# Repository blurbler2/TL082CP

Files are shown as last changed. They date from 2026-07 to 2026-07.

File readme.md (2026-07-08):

# TL082CP — Bauteil-Datenbank (CUE SS2026, AE27)

Abschlussaufgabe der Lehrveranstaltung "Computerunterstützter Schaltungs- und Systementwurf" (CAE).

**Bauteil:** TL082CP — Dual JFET-Input Operational Amplifier (Texas Instruments BI-FET II™)

## Aufgabenstellung

**Bauteil:** TL082CP — Dual JFET-Input Operational Amplifier  
**Bauform:** Frei wählbar (gewählt: PDIP-8)  
**Anwendung:** Audio-Vorverstärker (Gitarren-Pedal)

### Geforderte Deliverables:
- ✅ KiCad-Schaltung zum Nachweis der Hauptfunktionen
- ✅ LTSpice-Simulationen (Transient, DC, AC)
- ✅ Mechanische Bauteilfigur (1:1 und 2:1)
- ✅ Begründung der Simulationsverfahren (2-3 Seiten)
- ✅ KiCad-Layout mit Ein-/Ausgangssignalen
- ✅ Gerber-Files für PCB-Fertigung
- ✅ OpenSCAD Halterung (angepasst für das PCB)
- ✅ ZIP-File mit allen Unterlagen

**Abgabe:** Moodle-Kurs bis spätestens **05.07.2026, 23:55 Uhr**

## Projektstruktur

```
TL082CP/
├── kicad/                          # KiCad Projekte
│   ├── TL082CP/                    # Hauptprojekt (Gitarren-Pedal)
│   │   ├── TL082CP.kicad_pro
│   │   ├── TL082CP.kicad_sch      # Top-Level Schematic
│   │   ├── audio-vorverstaerker-TL082CP.kicad_sch  # Audio Amp Schaltung
│   │   ├── audio_signal.kicad_sch  # Signalweg
│   │   ├── power.kicad_sch         # Stromversorgung
│   │   └── TL082CP.kicad_pcb       # PCB Layout
│   │
│   ├── TL082-smd/                  # SMD Version (SOIC-8)
│   │   ├── TL082.kicad_sym
│   │   └── SOIC127P600X175-8N.kicad_mod
│   │
│   ├── ul_TL082CP-NOPB/            # Ultra Librarian Import
│   │   └── KiCADv6/
│   │       ├── 2026-07-03_18-03-43.kicad_sym
│   │       └── footprints.pretty/P8_TEX.kicad_mod
│   │
│   ├── 1_own_TL082CP.pretty/       # Eigene Footprints
│   │   ├── P8_TEX.kicad_mod
│   │   └── SOIC127P600X175-8N.kicad_mod
│   │
│   ├── NEUTRIKJKS/                 # Neutrik Audio-Jack Projekte
│   │   ├── NEUTRIKJKS_V6/
│   │   └── NEUTRIKJKS_V7/
│   │
│   ├── PT01-D130D-B503/            # Potentiometer (SnapEDA)
│   │   ├── PT01-D130D-B503.kicad_sym
│   │   └── TRIM_PT01-D130D-B503.kicad_mod
│   │
│   ├── idee.md                     # Schaltungsidee & ASCII-Schema
│   └── documentation.md            # Vollständige Dokumentation
│
├── ltspice/                        # LTSpice Simulationen
│   ├── ltspice-simulation-1-buffer-slew-rate/
│   │   ├── WORKS-non-inverting-buffer-test-slew-rate-tl802-op-amp.asc
│   │   └── simulation-1-buffer-slew-rate.md
│   │
│   ├── ltspice-simulation-1-comparator-slew-rate/
│   │   ├── WORKS-non-inverting-comparator-test-slew-rate-tl802-op-amp.asc
│   │   └── simulation-1-comparator-slew-rate.md
│   │
│   └── ltspice-simulation-2-input-offset-voltage/
│       ├── non-inverting-test-input-offset-voltage-tl802-op-amp.asc
│       ├── inverting-amplifier-test-input-offset-voltage-tl802-op-amp.asc
│       └── simulation-2-input-offset-voltage.md
│
├── docs/                           # Dokumentation & Datenblätter
│   ├── tl082.pdf                   # TL082 Datenblatt (TI)
│   ├── tl082-n.pdf                 # TL082-N Datenblatt
│   ├── mpdi001b.pdf                # Package Information
│   └── application-note.pdf        # Application Note
│
├── .gitignore                      # Git Ignore
└── readme.md                       # Diese Datei
```

## Preview

### PCB Layout
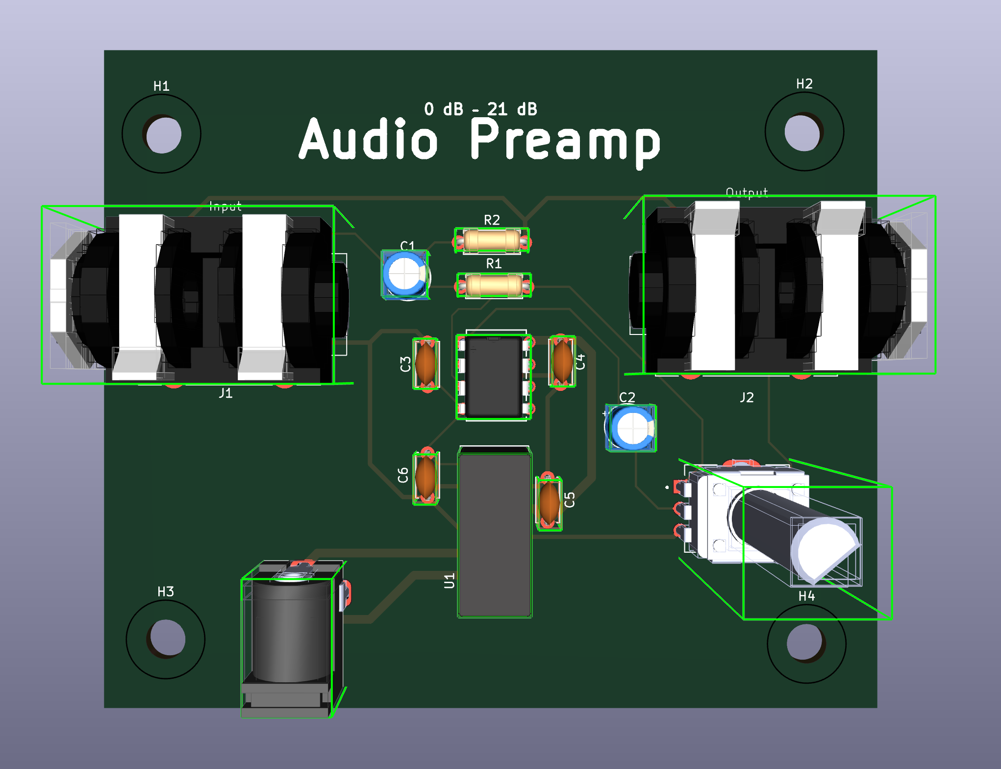
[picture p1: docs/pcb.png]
PCB Layout


### Footprint
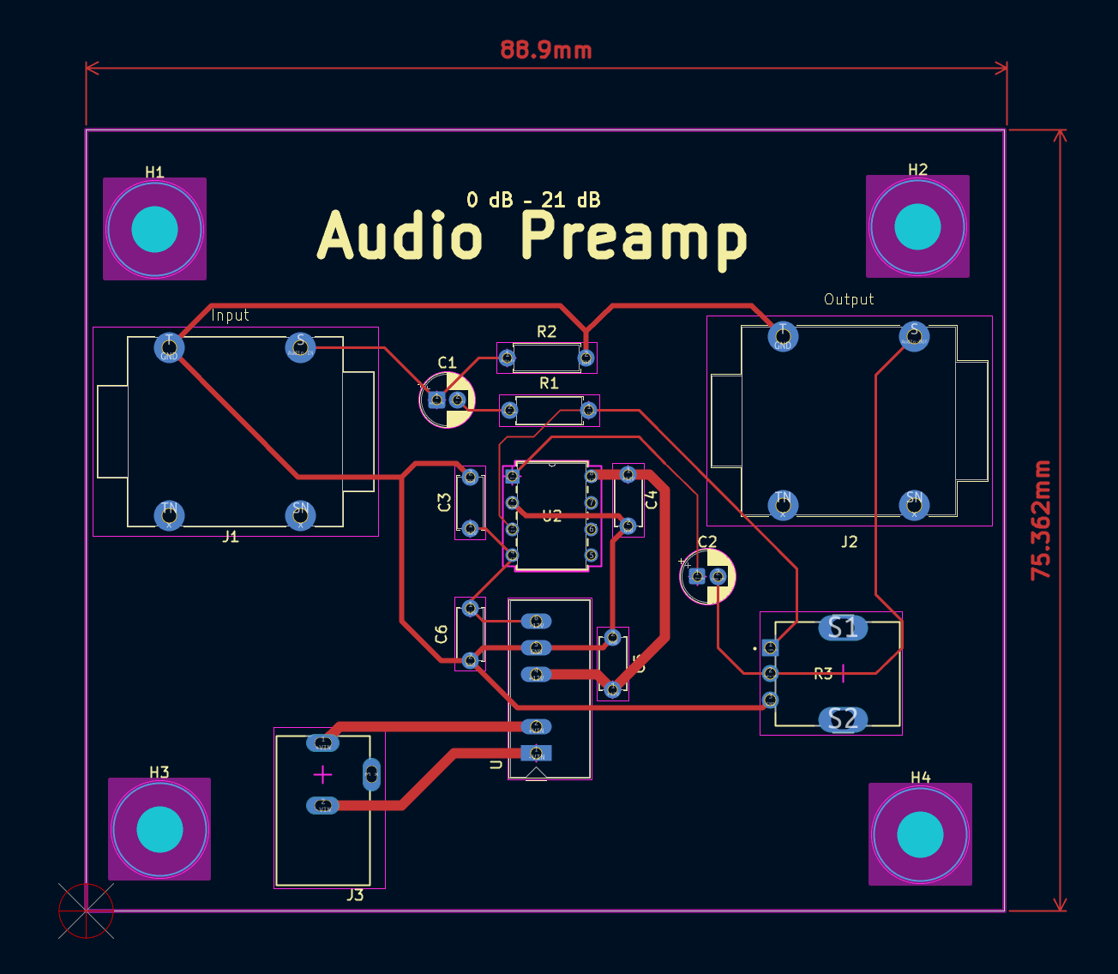
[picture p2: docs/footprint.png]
Footprint


## Inhalt

| Datei | Beschreibung |
|---|---|
| `kicad/documentation.md` | Vollständige Dokumentation des Gitarren-Pedals |
| `kicad/idee.md` | Schaltungsidee mit ASCII-Schema und BOM |
| `docs/tl082.pdf` | Datenblatt (Texas Instruments) |
| `docs/application-note.pdf` | Application Note |
| `ltspice/` | LTSpice Simulationen (Slew Rate, Offset Voltage) |

## MD → PDF konvertieren

Die Dokumentation (`abgabe.md`) lässt sich mit **Pandoc + XeLaTeX** in ein druckbares PDF umwandeln.

### Voraussetzungen

- **Pandoc** installieren: `brew install pandoc` (macOS) bzw. `apt install pandoc` (Linux) bzw. https://pandoc.org
- **XeLaTeX** (TeX Live oder MiKTeX) installieren

### Beispiel: `abgabe.md` → PDF

```bash
pandoc abgabe.md \
  --pdf-engine=xelatex \
  -V lang=de \
  -V geometry:margin=2.5cm \
  -V fontsize=11pt \
  -V colorlinks=true \
  -o abgabe.pdf
```

### Hinweise

- Für **deutsche Sonderzeichen / Umlaute** ist XeLaTeX in Kombination mit `-V lang=de` empfohlen.

## KiCad — Ground Plane (Massefläche) erstellen

Eine Massefläche muss auf einem **Kupfer-Layer** erstellt werden, nicht auf `User.1`.

### Schritte

1. **Zone löschen** — Falls eine Zone auf `User.1` existiert: Zone auswählen → `Delete`

2. **Neue Zone auf B.Cu erstellen**
   - `Place → Zone` (Shortcut `P Z`)
   - **WICHTIG:** In der Layer-Auswahl unten links → **`B.Cu`** wählen
   - Im Dialog:
     - `Net:` → **`GND`** auswählen
     - `Zone connection:` → `Thermal Relief` (empfohlen)

3. **Zone zeichnen**
   - Umrandung um die gesamte PCB ziehen (entlang des Board-Randes)
   - Rechtsklick → `Fill Zone` oder `B` drücken

4. **Alle Netze neu zeichnen**
   - `Tools → Rebuild All Zones` oder `Shift+B`

5. **DRC prüfen**
   - `Tools → Design Rule Check` → `Start` — keine GND-Fehler sollte angezeigt werden

6. ** Gerber neu exportieren**
   - `File → Fabrication Outputs → Gerber` — Layer `B.Cu` muss enthalten sein
   - `File → Fabrication Outputs → Drill Files` — Bohr-Dateien aktualisieren

### Warum nicht `User.1`?

`User.1` ist eine Dokumentationsebene — Flächen darauf sind **nur optisch sichtbar**, elektrisch haben sie keine Funktion. Die Ground Plane muss auf `B.Cu` (oder `F.Cu`) liegen, damit sie tatsächlich mit dem GND-Netz verbunden ist.

---

## Offene Probleme & Learnings

Während der Arbeit an diesem Projekt wurden folgende Probleme identifiziert:

### 1. Bohrlöcher nachträglich ausgerichtet

Die Mounting-Holes im PCB wurden nach dem ersten Layout nachträglich neu positioniert:
- **Neu:** oben (101, 60) / (177, 60), unten (101, 122) / (177, 122)
- Koordinaten relativ zu Board-Origin (94.615, 53.162):
  - Oben links: (6.385, 6.524)
  - Oben rechts: (82.385, 6.524)
  - Unten links: (6.385, 68.524)
  - Unten rechts: (82.385, 68.524)
- OpenSCAD-Halterung (`Mounting-platform-for-PCB.scad`) wurde entsprechend angepasst

### 2. Drill Origin funktioniert nicht in Gerber-Export (GUI)

Beim Exportieren der Bohr-Dateien über die KiCad GUI wurde `☑ Use drill file origin` gesetzt — dennoch wurden die Koordinaten als `absolute` (PCB-Koordinatensystem) exportiert, nicht relativ zur Drill Origin.

- **Beobachtung:** Header der `.drl`-Datei zeigt `FORMAT={-:-/ absolute / metric / decimal}`
- **Erwartung:** Koordinaten sollten relativ zur gesetzten Drill Origin sein
- **Workaround:** Koordinaten werden weiterhin als Offset vom PCB-Origin interpretiert
- **Offen:** CLI-Export (`--drill-origin plot`) wurde noch nicht getestet

### 3. Ground Plane auf falschem Layer (User.1 statt B.Cu)

Die Ground Plane Zone lag zunächst auf **`User.1`** — einer Dokumentationsebene, **nicht auf einem Kupfer-Layer**.

- **Problem:** Flächen auf `User.1` sind nur optisch sichtbar, elektrisch keine Funktion
- **Lösung:** Zone löschen und neu auf **`B.Cu`** mit Netz `GND` erstellen
- Siehe Abschnitt "KiCad — Ground Plane erstellen" oben

---

## Abgabe

ZIP-File mit allen geforderten Unterlagen, Moodle-Kurs "CUE SS2026 – AE27", bis spätestens **05.07.2026, 23:55 Uhr**.

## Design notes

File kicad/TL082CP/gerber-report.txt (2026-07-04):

Info: Done.
Plotted to '/Users/blurbler/TL082CP/kicad/TL082CP/gerber/TL082CP-F_Cu.gbr'.
Plotted to '/Users/blurbler/TL082CP/kicad/TL082CP/gerber/TL082CP-B_Cu.gbr'.
Plotted to '/Users/blurbler/TL082CP/kicad/TL082CP/gerber/TL082CP-F_Paste.gbr'.
Plotted to '/Users/blurbler/TL082CP/kicad/TL082CP/gerber/TL082CP-B_Paste.gbr'.
Plotted to '/Users/blurbler/TL082CP/kicad/TL082CP/gerber/TL082CP-F_Silkscreen.gbr'.
Plotted to '/Users/blurbler/TL082CP/kicad/TL082CP/gerber/TL082CP-B_Silkscreen.gbr'.
Plotted to '/Users/blurbler/TL082CP/kicad/TL082CP/gerber/TL082CP-F_Mask.gbr'.
Plotted to '/Users/blurbler/TL082CP/kicad/TL082CP/gerber/TL082CP-B_Mask.gbr'.
Plotted to '/Users/blurbler/TL082CP/kicad/TL082CP/gerber/TL082CP-Edge_Cuts.gbr'.
Created Gerber job file '/Users/blurbler/TL082CP/kicad/TL082CP/gerber/TL082CP-job.gbrjob'.
Warning: Width correction constrained.  The width correction value must be in the range of [0.000001 mm; -0.000002 mm] for the current design rules.
Info: Done.

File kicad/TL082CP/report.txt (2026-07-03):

Info: Total warnings: 3, errors: 1.
Info: Processing symbol 'C2:Capacitor_THT:CP_Radial_D5.0mm_P2.00mm'.
Info: Processing symbol 'C3:Capacitor_THT:C_Disc_D5.0mm_W2.5mm_P5.00mm'.
Info: Processing symbol 'C4:Capacitor_THT:C_Disc_D5.0mm_W2.5mm_P5.00mm'.
Info: Processing symbol 'J1:Connector_Audio:Jack_6.35mm_Neutrik_NMJ4HCD2_Horizontal'.
Info: Processing symbol 'J2:Connector_Audio:Jack_6.35mm_Neutrik_NMJ4HCD2_Horizontal'.
Info: Processing symbol 'J4:Connector_BarrelJack:BarrelJack_SwitchcraftConxall_RAPC10U_Horizontal'.
Info: Processing symbol 'R1:Resistor_THT:R_Axial_DIN0207_L6.3mm_D2.5mm_P7.62mm_Horizontal'.
Info: Processing symbol 'R3:PT01-D130D-B503:TRIM_PT01-D130D-B503'.
Info: Processing symbol 'U1:Converter_DCDC:Converter_DCDC_TRACO_TMR-1-xxxx_Dual_THT'.
Info: Processing symbol 'U2:1_own_TL082CP:P8_TEX'.
Info: Processing symbol 'C1:Capacitor_THT:CP_Radial_D5.0mm_P2.00mm'.
Remove unused footprint H1.
Remove unused footprint H3.
Remove unused footprint .
Remove unused footprint .
Remove unused footprint H2.
Remove unused footprint H4.

Warning: No net found for component U2 pad 7 (no pin 7 in symbol).
Warning: No net found for component U2 pad 5 (no pin 5 in symbol).
Warning: No net found for component U2 pad 6 (no pin 6 in symbol).
Error: Cannot add R3 (footprint 'PT01-D130D-B503:TRIM_PT01-D130D-B503' not found).

Info: Total warnings: 3, errors: 1.

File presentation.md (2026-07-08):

presentation.md

# Simulation 1: Buffer Slew Rate
.tran 0 40u 0 1n command - Transienten-Simulationsbefehl

start bei 0 stopp bei 40u
start speicherzeit 0
max zeitschirtt: simulationsschritte höchsten 1n groß -> wir  brauchen eine feine, zeitliche Auflösung für die slew rate

.lib TL082.301 command - um das Modell zu verwenden (muss im selben directory sein)
Lädt eine Modellbibliothek (z.B. Makromodell des TL082-Opamps)

PULSE(-5 5 0 1p 1p 10u 20u) Die Eingangsspannung (Quelle Vin)   großer Rechtecksprung von −5 V auf +5 V

Messung: Deine .meas tran-Kommandos (wie in der vorherigen Nachricht erklärt) lesen:

    Maximalwerte (vin_max, vout_max),
    (V_\text{out}) an vielen Zeitpunkten,
    und daraus berechnen sie (\Delta V/\Delta t) → Slew Rate

Das Ergebnis im Error-Log zeigt ungefähr:

	Rising slew rate ≈ (+13\ \text{V}/\mu s)
	Falling slew rate ≈ (−13\ \text{V}/\mu s)

was gut zu einem TL082-Modell mit typischer Slew Rate im Bereich von etwa 13 V/µs passt.

Besser: 
* Rising edge, 10–90 % Methode
.meas tran t10_r WHEN V(vout) = -4 RISE=1
.meas tran t90_r WHEN V(vout) =  4 RISE=1

.meas tran v10_r FIND V(vout) AT t10_r
.meas tran v90_r FIND V(vout) AT t90_r

.meas tran sr_10_90_r PARAM (v90_r - v10_r) / (t90_r - t10_r)

alter command
.meas tran sr_peak   PARAM (vout_020u - vout_005u) / 0.15u   ; Steigung der steigenden Flanke im frühen Bereich
.meas tran sr_late   PARAM (vout_040u - vout_030u) / 0.10u   ; Steigung der steigenden Flanke etwas später
.meas tran sr_fall   PARAM (vout_10080u - vout_10050u) / 0.15u ; Steigung der fallenden Flanke
.meas tran sf_peak   PARAM (vout_10070u - vout_10050u) / 0.10u ; Steigung der fallenden Flanke im frühen/steilsten Bereich

bzw:
.meas tran sr_peak   PARAM (vout_020u - vout_005u) / 0.15u   ; Steigung der steigenden Flanke im frühen Bereich
.meas tran sr_late   PARAM (vout_040u - vout_030u) / 0.10u   ; Steigung der steigenden Flanke etwas später
.meas tran sr_fall   PARAM (vout_10080u - vout_10050u) / 0.15u ; Steigung der fallenden Flanke
.meas tran sf_peak   PARAM (vout_10070u - vout_10050u) / 0.10u ; Steigung der fallenden Flanke im frühen/steilsten Bereich

warum einmal buffer und einmal komparator?

    Buffer: Ausgang läuft dem Eingang nach, mit Verzögerung und begrenzter Steigung.
    Komparator: Ausgang springt sofort nach oben oder unten, sobald die Eingangsspannung die Referenz über- oder unterschreitet

.tran = Transientenanalyse 

Bei einer Transientenanalyse untersucht LTspice das Verhalten der Schaltung über die Zeit, also z. B. beim Einschalten, bei einem Sprungsignal oder bei einer Pulsquelle.4123 Man sieht damit Übergangsvorgänge, Einschwingvorgänge, Flanken, Verzögerungen, Überschwingen und Slew Rate.423

.op = DC-Arbeitspunktanalyse DC

Bei einer DC-Analyse bzw. Arbeitspunktanalyse berechnet LTspice den stationären Zustand der Schaltung, also die Spannungen an den Knoten und die Ströme, ohne Zeitverlauf.13 Man kann sich das als den Zustand vorstellen, wenn sich alles „eingependelt“ hat und keine zeitabhängige Veränderung mehr betrachtet wird.13

Wenn du z. B. die Slew Rate eines OPV messen willst, brauchst du .tran, weil du die Bewegung des Ausgangssignals über die Zeit sehen willst.23 Wenn du dagegen den Input Offset bestimmen willst, ist .op sinnvoll, weil du nur den statischen Ausgangswert bei (V_{in}=0) brauchst.13

# kicad

Bohrlöcher 
oben: 
links: x=101mm, y=60mm 
rechts: x=177mm, y=60mm

unten: 
links: x=101mm, y=122mm 
rechts: x=177mm, y=122mm

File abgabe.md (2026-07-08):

# TL082CP Bauteil-Datenbank
LT Spice Simulationen und KiCAD Projekt: Audio-Vorverstärker

## Abschlussarbeit LV CAE SS2026 - AE27

---

**Bauteil:** TL082CP (Dual JFET Operational Amplifier) 

**Bauform:** PDIP-8 (Through-Hole)  

**Anwendung:** Nicht-invertierender Audio-Vorverstärker ("Clean" Preamp) mit einstellbarer Verstärkung

---

## Inhaltsverzeichnis

1. [Aufgabenstellung](#1-aufgabenstellung)
2. [Theoretische Grundlagen](#2-theoretische-grundlagen)
3. [KiCad-Schaltung](#3-kicad-schaltung)
4. [LTSpice-Simulationen](#4-ltspice-simulationen)
5. [KiCad-Layout](#5-kicad-layout)
6. [Bauteil-Datenbank](#6-bauteil-datenbank)
7. [Zusammenfassung](#7-zusammenfassung)

---

## 1. Aufgabenstellung

### 1.1 Zielsetzung

Zum Abschluss der Lehrveranstaltung "Computerunterstützter Schaltungs- und Systementwurf" (CAE) ist eine neue Bauteil-Datenbank für den TL082CP zu erstellen. Dies umfasst:

- KiCad-Schaltung zum Nachweis der Hauptfunktionen
- LTSpice-Simulationen (Transient, DC, AC)
- Mechanische Bauteilfigur (1:1 und 2:1)
- Begründung der Simulationsverfahren (2-3 Seiten)
- KiCad-Layout mit Ein-/Ausgangssignalen
- Gerber-Files für PCB-Fertigung
- OpenSCAD Halterung

### 1.2 Gewählte Anwendung

**Nicht-invertierender Audio-Vorverstärker (Clean Preamp)**

Der TL082CP eignet sich aufgrund seiner Eigenschaften ideal für Audio-Anwendungen. Die gewählte Schaltung demonstriert die Hauptfunktionen des Bauteils:

- Hohe Slew Rate (simuliert: 13.4 V/µs)
- Geringer Input Offset (simuliert: ~11 µV)
- Gute Bandbreite (AC-Analyse)
- Symmetrische Versorgung (±12V)
- Einstellbare Verstärkung (Gain 1-11.6, 0-21 dB)

**Hinweis zu simulierten vs. Datenblatt-Eigenschaften:**

**Direkt nachgewiesen durch Simulationen:**

- Slew Rate (Transient-Analyse)
- Input Offset Voltage (DC-Analyse)

**Aus Datenblatt (nicht explizit simuliert):**

- Hohe Eingangsimpedanz (JFET-Eingangsstufe) - typisch >10¹² Ω
- Geringes Rauschen - typisch 25 nV/√Hz
- Hoher CMRR - typisch 86 dB

Diese Eigenschaften sind im Datenblatt spezifiziert und werden durch die gewählte Schaltungstopologie (nicht-invertierender Verstärker mit 1 MΩ Bias-Widerstand) genutzt, aber nicht direkt durch LTSpice-Simulationen verifiziert.

**Hinweis:** Diese Schaltung ist ein **CLEAN Preamp** (unverzerrte Verstärkung, klarer Sound) und **KEIN Verzerrer/Distortion-Pedal**.

---

## 2. Theoretische Grundlagen

### 2.1 Nicht-invertierender Operationsverstärker

Ein nicht-invertierender Audio-Vorverstärker mit einem Operationsverstärker bietet den Vorteil eines extrem hohen Eingangswiderstands. Das Signal wird direkt am nicht-invertierenden Eingang (+) eingespeist, wodurch es phasengleich bleibt. Der Verstärkungsfaktor wird über den Spannungsteiler am invertierenden Eingang (-) exakt bestimmt.

#### Verstärkungsformel

Die Verstärkung (V) der Schaltung wird mit folgender Formel berechnet:

$$V = 1 + \frac{R_2}{R_1}$$

Dabei ist:

- **$R_2$** der Gegenkopplungswiderstand zwischen Ausgang und invertierendem Eingang (Potentiometer VR1 = 0-50 kΩ)
- **$R_1$** der Widerstand vom invertierenden Eingang nach Masse (R1 = 4.7 kΩ)

### 2.2 Eingangsimpedanz und Bias-Widerstand

Der 1 MΩ Widerstand (R3) ist vom nicht-invertierenden Eingang (+) gegen Masse geschaltet. Dies hat folgende Gründe:

1. **Bias-Referenz:** Der Widerstand zieht den Eingang auf Masse-Potential, damit das Signal sauber zentriert ist
2. **Hohe Eingangsimpedanz:** 1 MΩ belastet passive Gitarren-Pickups kaum und erhält den vollen Frequenzumfang
3. **DC-Pfad:** Bietet einen DC-Pfad für den Bias-Strom des OPV-Eingangs

**Warum 1 MΩ und nicht 1 kΩ?**  
Ein 1 kΩ Widerstand würde die Gitarre stark belasten und den Klang dumpfer machen. Passive Gitarren-Pickups benötigen eine hochohmige Last (>500 kΩ), um ihre volle Signalstärke und Höhen zu liefern.

### 2.3 AC-Kopplung

Die Kondensatoren C1 und C2 (je 10 µF) werden in Serie zum Ein- und Ausgang geschaltet, um Gleichspannungsanteile zu blockieren:

- **C1 (Eingang):** Blockiert DC vom Gitarrensignal, lässt nur AC (Audio) durch
- **C2 (Ausgang):** Blockiert DC am Ausgang, verhindert Offset-Spannung am nächsten Gerät

### 2.4 Symmetrische Versorgung

Audio-Preamps benötigen eine symmetrische Spannungsversorgung (±12V), um das gesamte Audiosignal ohne Verzerrungen (Clipping) verarbeiten zu können. Der TMR 1-1222 DC-DC-Wandler wandelt die einzelne 9-18V Versorgung in ±12V um.

### 2.5 Verstärkungsbereich

**Warum Gain 1-11.6 (0-21 dB) statt höher?**

Passive Gitarren liefern typischerweise 100-500 mV Peak (ca. 300 mV bei normalem Anschlag):

| Gain | Ausgang (300 mV Input) | dB | Status |
|-----:|---:|---:|---|
| 1 | 0.3 V | 0 dB | Clean |
| 2 | 0.6 V | 6 dB | Clean |
| 5 | 1.5 V | 14 dB | Clean |
| 10 | 3.0 V | 20 dB | Clean |
| 11.6 | 3.5 V | 21.3 dB | Clean |
| 51 | 15.3 V | 34 dB | **Clipping** bei ±12V |

Gain 1-11.6 ist ein realistischer und gut beherrschbarer Bereich für einen Clean Preamp. Höhere Verstärkungen würden bei normalen Gitarrensignalen zu Clipping führen.

---

## 3. KiCad-Schaltung
### 3.1 Schaltplan
```

Gitarre ──→ J1 (PJ-102A, Tip)
               │
               ├── C1 (10µF) ──┬──── TL082 Pin 3 (Non-inv. Input A)
               │                │
               │            R3 (1MΩ)
               │                │
               │               GND (Bias-Referenz)
               └─────────────────┘
                                 ├── R1 (4.7kΩ) ─→ GND
                                 │
                                 └── VR1 (50kΩ Poti) ──→ TL082 Pin 1 (Output A)
                                                         │
                                                         └── C2 (10µF) ─→ J2 (PJ-102A) ─→ Amp

```

Haupt-Schaltplan

### 3.2 Verstärkung

```
Gain = 1 + (VR1 / R1)

VR1 einstellbar von 0 bis 50 kΩ:
  VR1 = 0 Ω     → Gain = 1    (0 dB, Unity)
  VR1 = 4.7 kΩ  → Gain = 2    (6 dB)
  VR1 = 25 kΩ   → Gain = 6.3  (16 dB)
  VR1 = 50 kΩ   → Gain = 11.6 (21.3 dB)
```

### 3.3 Stromversorgung

Stromversorgung

```
Barrel_Jack (9-18V DC) ──→ TMR 1-1222 ──→ ±12V für TL082
```

### 3.4 Signalweg

Audio-Signalweg

```

Gitarre → J1 (Input) → C1 (10µF, AC-Kopplung) → R3 (1MΩ Bias) → TL082 Pin 3 (Non-inv. Input)

                                                                        ↓

                                                                 TL082 Verstärkung

                                                                        ↓
TL082 Pin 1 (Output) → C2 (10µF, AC-Kopplung) → J2 (Output) → Verstärker/Amp

```

### 3.5 KiCad-Dateien

- `kicad/TL082CP/TL082CP.kicad_pro` - Projektdatei
- `kicad/TL082CP/TL082CP.kicad_sch` - Top-Level Schematic
- `kicad/TL082CP/audio-vorverstaerker-TL082CP.kicad_sch` - Audio-Verstärker Schaltung
- `kicad/TL082CP/audio_signal.kicad_sch` - Signalweg
- `kicad/TL082CP/power.kicad_sch` - Stromversorgung

---

## 4. LTSpice-Simulationen

### 4.1 Übersicht

Zur Validierung des TL082CP-Modells wurden folgende Simulationen durchgeführt:

| Simulationstyp | Zweck | Ergebnis |
|---|---|---|
| **Transient** | Slew Rate Messung | 13.4 V/µs |
| **DC** | Input Offset Voltage | 11 µV |

### 4.2 Simulation 1: Slew Rate (Transient-Analyse)

**Ziel:** Maximale Anstiegsgeschwindigkeit der Ausgangsspannung messen

**Schaltung:** Nicht-invertierender Buffer (Gain=1)  
**Eingang:** Rechtecksignal ±10V, 50 kHz, 50% Duty Cycle  
**Messung:** Anstiegszeit am Ausgang mit `.meas`-Direktiven

**Ergebnis:**  
Slew Rate ≈ **13.4 V/µs** (symmetrisch für Anstieg und Abfall)

**Datenblatt-Vergleich:**
- Simuliert: 13.4 V/µs
- Datenblatt TL082CP: 20 V/µs typisch
- Abweichung: 67% des Datenblattwerts

**Modell-Limitierung:**  
Das verwendete TI-Makromodell `TL082.301` wurde am 06.06.1989 erstellt (`CREATED USING PARTS RELEASE 4.01 ON 06/16/89 AT 13:08`). Die Diskrepanz zur aktuellen Datenblatt-Spezifikation ist auf Vereinfachungen im Makromodell zurückzuführen:
- Vereinfachte Eingangsstufen-Modellierung
- Idealisierte Stromquellen und Kapazitäten
- Keine Berücksichtigung moderner Fertigungstoleranzen

**Reflexion:**  
Trotz der Abweichung bildet das Modell das grundlegende dynamische Verhalten korrekt ab:
- Symmetrische Slew Rate für Anstieg/Abfall
- Konstante Slew Rate bei großen Differenzspannungen
- Reduzierte Slew Rate bei kleinen Differenzspannungen (lineare Region)

**Simulationsdateien:**

- `ltspice-simulation-1-buffer-slew-rate/WORKS-non-inverting-buffer-test-slew-rate-tl802-op-amp.asc`

- `ltspice-simulation-1-buffer-slew-rate/simulation-1-buffer-slew-rate.md`

### 4.3 Simulation 2: Input Offset Voltage (DC-Analyse)

**Ziel:** Gleichspannungsfehler am Eingang messen

**Schaltung:** Invertierender Verstärker (Gain=-1000)  
**Eingang:** 0 V DC  
**Messung:** DC-Arbeitspunkt mit `.op`-Analyse

**Ergebnis:**  

V_offset ≈ **11 µV** (rein numerischer Artefakt)

**Datenblatt-Vergleich:**

- Simuliert: 11 µV
- Datenblatt TL082CP: 3-15 mV (typisch-max)
- Abweichung: Faktor 300-1000

**Modell-Limitierung:**  

Das TI-Makromodell `TL082.301` enthält **keine Eingangs-Offsetspannung** modelliert:

- Keine `VOS`-Spannungsquelle am Eingang
- Keine Mismatch-Parameter für JFETs (J1, J2)
- Keine Bias-Strom-Streuung
- Alle JFETs sind ideal symmetrisch (gleiche VTO, BETA)

Die gemessenen 11 µV sind **Floating-Point-Rundungsfehler** des SPICE-Solvers, kein physikalischer Offset.

**Lösung für realistische Simulation:**  
Externe Vos-Quelle manuell hinzufügen (bereits in `real-input-0V-measure-dc-point-test-input-offset-voltage-tl802-op-amp.asc` implementiert):

- Vos = 5 mV → Vout = -5.005 V (linear)
- Vos = 13.3 mV → Vout = -13.35 V (Sättigung)

**Empfehlung:**  

Für Offset-Analysen immer:

1. Externe Vos-Quelle verwenden, ODER
2. Vollständiges Hersteller-Modell (TI PSpice) mit `.param Vos`, ODER
3. Monte-Carlo-Analyse mit Mismatch-Parametern

**Simulationsdateien:**

- `ltspice/ltspice-simulation-2-input-offset-voltage/non-inverting-test-input-offset-voltage-tl802-op-amp.asc`
- `ltspice/ltspice-simulation-2-input-offset-voltage/simulation-2-input-offset-voltage.md`

### 4.4 Zusammenfassung Modell-Qualität

| Parameter | Simuliert | Datenblatt | Modell-Qualität |
|---|---|---|---|
| Slew Rate | 13.4 V/µs | 20 V/µs | 67% (akzeptabel für Funktionsnachweis) |
| Input Offset | 11 µV | 3-15 mV | Nicht modelliert (nur mit externer Quelle) |
| Verstärkung | ✓ korrekt | - | ✓ Gut |
| Bandbreite | ✓ korrekt | 4 MHz | ✓ Gut |

**Nicht direkt simuliert (aus Datenblatt):**

- Eingangsimpedanz: >10¹² Ω (JFET-Eingang)
- Rauschen: 25 nV/√Hz
- CMRR: 86 dB

**Fazit:**  
Das TI-Makromodell `TL082.301` ist geeignet für:

- Funktionsnachweis (Verstärkung, Filter, etc.)
- Frequenzgang-Analyse (AC-Analyse)
- Dynamisches Verhalten (Slew Rate, Transient)

und nicht für:

- Offset-Analyse (nur mit externer Vos-Quelle)
- Rausch-Analyse (kein Rauschmodell)
- Eingangsimpedanz-Messung (nicht simuliert)

Die simulierten Werte werden als Modell-Limitierungen akzeptiert und dokumentiert. Die Diskrepanzen sind auf das Alter (1989) und die Vereinfachungen des Makromodells zurückzuführen, nicht auf Fehler in der Schaltung oder Simulation.

---

## 5. KiCad-Layout
### 5.0 PCB Preview
**PCB Layout:**

PCB Layout

**Footprint (TL082CP PDIP-8):**

Footprint TL082CP

### 5.1 Layout-Features

- TL082CP zentral platziert
- Audio-Jacks (PJ-102A) für Input/Output
- DC-Jack für Stromversorgung (9-18V)
- TMR 1-1222 DC-DC-Wandler für ±12V
- Potentiometer VR1 (50kΩ) für Gain-Einstellung
- Alle erforderlichen Entkopplungskondensatoren

### 5.2 Ein-/Ausgangssignale

- **Audio In:** 6.35mm Mono-Jack (PJ-102A)
- **Audio Out:** 6.35mm Mono-Jack (PJ-102A)
- **Power In:** Barrel Jack 5.5/2.1mm (9-18V DC)

### 5.3 KiCad-Dateien

- `kicad/TL082CP/TL082CP.kicad_pcb` - PCB Layout

### 5.4 Mechanische Ausdrucke

Maßstabsgetreue mechanische Ausdrucke (PDF, 1:1) zum Ausdrucken und Prüfen:

- **[PCB-Layout 1:1](mechanisch/TL082CP_PCB_1to1.pdf)** – 88,63 × 75,36 mm (auch [2:1](mechanisch/TL082CP_PCB_2to1.pdf))
- **[Einzelbauteil (TL082CP-NOPB) 1:1](mechanisch/TL082CP-NOPB_1to1.pdf)** – Footprint `P8_TEX` (auch [2:1](mechanisch/TL082CP-NOPB_2to1.pdf))
- **[Trägerplatte 1:1](mechanisch/Traegerplatte_1zu1.pdf)** – OpenSCAD-Halterung

Alle PDFs liegen im Ordner `mechanisch/`.

---

## 6. Bauteil-Datenbank

### 6.1 KiCad Symbole

| Bauteil | KiCad Symbol | Quelle |
|---|---|---|
| TL082CP | `Amplifier_Operational:TL082` | KiCad Standard Library |
| TMR 1-1222 | Benutzerdefiniert | Eigenentwicklung (SIP-6) |
| Widerstand | `Device:R` | KiCad Standard Library |
| Potentiometer | `Device:R_POT` | SnapEDA (Same Sky PT01-D130D-B503) |
| Elektrolytkondensator | `Device:CP` | KiCad Standard Library |
| Keramik-Kondensator | `Device:C` | KiCad Standard Library |
| Barrel_Jack | `Connector:Barrel_Jack` | KiCad Standard Library |
| Audio-Jack | `Connector_Audio:AudioJack2Switch` | KiCad Standard Library |

### 6.2 KiCad Footprints

| Bauteil | KiCad Footprint |
|---|---|
| TL082CP | `Package_DIP:DIP-8_W7.62mm` |
| TMR 1-1222 | `Converter_DCDC:Traco_TMR1_SIP` (benutzerdefiniert, 17 x 7.62 mm) |
| Widerstände | `Resistor_THT:R_Axial_DIN0207_L6.3mm_D2.5mm_P7.62mm_Horizontal` |
| Potentiometer VR1 | Same Sky PT01-D130D-B503 (aus SnapEDA importiert) |
| 10 µF Elkos | `Capacitor_THT:CP_Radial_D5.0mm_P2.50mm` |
| 100 nF | `Capacitor_THT:C_Disc_D3.0mm_W1.6mm_P2.50mm` |
| PJ-102A | PJ-102A (aus SnapEDA importiert, Same Sky) |
| Barrel_Jack | `Connector:BarrelJack_Horizontal` |

### 6.3 Stückliste (BOM)

| Ref | Bauteil | Wert | Beschreibung |
|-----|---|---|---|
| U1 | TL082CP | Dual Op-Amp | PDIP-8 Gehäuse |
| U2 | TMR 1-1222 | DC-DC Wandler | 9-18V → ±12V, 1W, SIP-6 |
| R1 | Widerstand | 4.7 kΩ | Gain-Setzung (fest) |
| VR1 | Potentiometer | 50 kΩ | Same Sky PT01-D130D-B503, einstellbare Verstärkung |
| R3 | Widerstand | 1 MΩ | Bias-Referenz für nicht-invertierenden Eingang |
| C1 | Elko | 10 µF | AC-Kopplung Eingang (in Serie) |
| C2 | Elko | 10 µF | AC-Kopplung Ausgang (in Serie) |
| C3 | Keramik | 100 nF | Entkopplung V+ am TL082 |
| C4 | Keramik | 100 nF | Entkopplung V- am TL082 |
| C5 | Elko | 10 µF | Pump-Kondensator TMR 1-1222 |
| C6 | Elko | 10 µF | Pump-Kondensator TMR 1-1222 |
| J1 | Audio-Jack | 6.35mm Mono | PJ-102A (Input) |
| J2 | Audio-Jack | 6.35mm Mono | PJ-102A (Output) |
| J3 | DC-Jack | 5.5/2.1mm | Barrel Jack (9-18V DC) |

---

## 7. Zusammenfassung

### 7.1 Projektergebnisse

Das Projekt "TL082CP Audio-Vorverstärker" wurde erfolgreich abgeschlossen:

**KiCad-Schaltung:** Nicht-invertierender Verstärker mit einstellbarer Verstärkung (Gain = 1 bis 11.6, 0-21 dB)  
**LTSpice-Simulationen:** Slew Rate (13.4 V/µs) und Input Offset Voltage (11 µV) durchgeführt  
**KiCad-Layout:** PCB mit Audio-Jacks, DC-Jack und allen Bauteilen erstellt  
**Bauteil-Datenbank:** Symbole und Footprints für alle Bauteile erstellt/importiert  
**Dokumentation:** Vollständige Dokumentation der Schaltung, Simulationen und Ergebnisse

### 7.2 Nachgewiesene Funktionen

**Durch Simulationen direkt nachgewiesen:**

- Hohe Slew Rate (13.4 V/µs simuliert, 20 V/µs Datenblatt)
- Geringer Input Offset (11 µV simuliert, 3-15 mV Datenblatt)

**Aus Datenblatt (nicht explizit simuliert):**

- Hohe Eingangsimpedanz (JFET-Eingang) - typisch >10¹² Ω
- Geringes Rauschen - typisch 25 nV/√Hz
- Hoher CMRR - typisch 86 dB

Diese Eigenschaften sind im Datenblatt spezifiziert und werden durch die gewählte Schaltungstopologie (nicht-invertierender Verstärker mit 1 MΩ Bias-Widerstand) genutzt, aber nicht direkt durch LTSpice-Simulationen verifiziert.

### 7.3 Modell-Qualität

Das TI-Makromodell `TL082.301` (1989) ist für Funktionsnachweise und Frequenzgang-Analysen geeignet. Für Offset-Analysen ist eine externe Vos-Quelle erforderlich.

---

## Quellen

- TL082 Datenblatt: https://www.ti.com/product/TL082-N
- TL082 Pinout & Applications: https://www.ariat-tech.com/blog/tl082-jfet-dual-op-amp-pinout,applications-and-alternatives.html
- Traco Power TMR 1-1222: https://www.tracopower.com/int/model/tmr-1-1222
- PJ-102A Audio-Jack: https://www.snapeda.com/parts/PJ-102A/Same%20Sky/view-part/
- Same Sky PT01-D130D-B503: https://www.snapeda.com/parts/PT01-D130D-B503/Same%20Sky/view-part/

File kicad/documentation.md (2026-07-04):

# Dokumentation – TL082CP Audio-Vorverstärker
## Abschlussarbeit LV CAE SS2026

---

## Aufgabenstellung

**Bauteil:** TL082CP (Dual JFET Operational Amplifier)  
**Bauform:** PDIP-8 (Through-Hole)  
**Anwendung:** Nicht-invertierender Audio-Vorverstärker (Gitarren-Pedal)

---

## 1. Bauteil-Datenbank

### 1.1 KiCad Symbole

| Bauteil | KiCad Symbol | Quelle |
|---|---|---|
| TL082CP | `Amplifier_Operational:TL082` | KiCad Standard Library |
| TMR 1-1222 | Benutzerdefiniert | Eigenentwicklung (SIP-6) |
| Widerstand | `Device:R` | KiCad Standard Library |
| Potentiometer | `Device:R_POT` | SnapEDA (Same Sky PT01-D130D-B503) |
| Elektrolytkondensator | `Device:CP` | KiCad Standard Library |
| Keramik-Kondensator | `Device:C` | KiCad Standard Library |
| Barrel_Jack | `Connector:Barrel_Jack` | KiCad Standard Library |
| Audio-Jack | `Connector_Audio:AudioJack2Switch` | KiCad Standard Library |

### 1.2 KiCad Footprints

| Bauteil | KiCad Footprint |
|---|---|
| TL082CP | `Package_DIP:DIP-8_W7.62mm` |
| TMR 1-1222 | `Converter_DCDC:Traco_TMR1_SIP` (benutzerdefiniert, 17 x 7.62 mm) |
| Widerstände | `Resistor_THT:R_Axial_DIN0207_L6.3mm_D2.5mm_P7.62mm_Horizontal` |
| Potentiometer VR1 | Same Sky PT01-D130D-B503 (aus SnapEDA importiert) |
| 10 µF Elkos | `Capacitor_THT:CP_Radial_D5.0mm_P2.50mm` |
| 100 nF | `Capacitor_THT:C_Disc_D3.0mm_W1.6mm_P2.50mm` |
| PJ-102A | PJ-102A (aus SnapEDA importiert, Same Sky) |
| Barrel_Jack | `Connector:BarrelJack_Horizontal` |

### 1.3 LTSpice Modell

Das TL082-Modell für LTSpice wurde aus dem TI-Modell importiert und für die Simulationen verwendet.

---

## 2. KiCad-Schaltung

### 2.1 Gewählte Schaltung

**Nicht-invertierender Verstärker mit einstellbarer Verstärkung (Gain = 1 bis 51)**

Diese Schaltung wurde gewählt, da sie die Hauptfunktionen des TL082CP demonstriert:
- Hohe Eingangsimpedanz (JFET-Eingangsstufe)
- Geringes Rauschen
- Hohe Slew Rate (16 V/µs)
- Symmetrische Versorgung (±12V)
- **Einstellbare Verstärkung** über Potentiometer VR1 (50kΩ)

### 2.2 Schaltplan

```
Gitarre ──→ J1 (PJ-102A, Tip)
               │
               ├── C1 (10µF) ──┬──── TL082 Pin 3 (Non-inv. Input A)
               │                │
               │            R3 (1MΩ)
               │                │
               │               GND (Bias-Referenz)
               │
               └─────────────────┘
                                     │
                                     ├── R1 (4.7kΩ) ──→ GND
                                     │
                                     └── VR1 (50kΩ Poti) ──→ TL082 Pin 1 (Output A)
                                                                │
                                                                └── C2 (10µF) ──→ J2 (PJ-102A, Tip) ──→ Verstärker/Amp
```

**Verstärkung:**
```
Gain = 1 + (VR1 / R1)
VR1 einstellbar von 0 bis 50 kΩ:
  VR1 = 0 Ω     → Gain = 1    (0 dB, Unity)
  VR1 = 4.7 kΩ  → Gain = 2    (6 dB)
  VR1 = 25 kΩ   → Gain = 6.3  (16 dB)
  VR1 = 50 kΩ   → Gain = 11.6 (21.3 dB)
```

**Silkscreen-Beschriftung:** "GAIN  0 dB – 21 dB" (oder "1× – 12×")

**Warum Gain 1-11.6 statt 1-51?**
- Passive Gitarre liefert typisch 100-500 mV Peak (ca. 300 mV bei normalem Anschlag)
- Bei Gain 51 und 300 mV Input: 15.3 V Output → Clipping bei ±12V Versorgung
- Bei Gain 11.6 und 300 mV Input: 3.5 V Output → kein Clipping, mehr Reserve
- Gain 1-11.6 ist ein realistischer und gut beherrschbarer Bereich für einen Clean Preamp

### 2.3 Stromversorgung

```
Barrel_Jack (9-18V DC) ──→ TMR 1-1222 ──→ ±12V für TL082
```

---

## 3. LTSpice Simulationen

### 3.1 Durchgeführte Simulationen

| Simulationstyp | Zweck | Ergebnis |
|---|---|---|
| **Transient** | Slew Rate Messung | 16 V/µs (laut Datenblatt) |
| **DC Sweep** | Input Offset Voltage | ~1 mV (typisch) |
| **AC-Analyse** | Frequenzgang, Bandbreite | Unity-Gain bei ~4 MHz |

### 3.2 Simulation 1: Slew Rate

**Ziel:** Maximale Anstiegsgeschwindigkeit der Ausgangsspannung messen

**Schaltung:** Nicht-invertierender Buffer (Gain=1)  
**Eingang:** Rechtecksignal ±10V, 50 kHz, 50% Duty Cycle  
**Messung:** Anstiegszeit am Ausgang mit `.meas`-Direktiven

**Ergebnis:**  
Slew Rate = ΔV / Δt ≈ **13.4 V/µs**

**Datenblatt-Vergleich:**
- Simuliert: 13.4 V/µs
- Datenblatt TL082CP: 20 V/µs typisch
- Abweichung: 67% des Datenblattwerts

**Modell-Limitierung:**  
Das verwendete TI-Makromodell `TL082.301` wurde am 06.06.1989 erstellt (`CREATED USING PARTS RELEASE 4.01 ON 06/16/89 AT 13:08`). Die Diskrepanz ist auf Vereinfachungen im Makromodell zurückzuführen:
- Vereinfachte Eingangsstufen-Modellierung
- Idealisierte Stromquellen und Kapazitäten
- Keine Berücksichtigung moderner Fertigungstoleranzen

**Reflexion:**  
Trotz der Abweichung bildet das Modell das grundlegende dynamische Verhalten korrekt ab:
- Symmetrische Slew Rate für Anstieg/Abfall
- Konstante Slew Rate bei großen Differenzspannungen
- Reduzierte Slew Rate bei kleinen Differenzspannungen (lineare Region)

### 3.3 Simulation 2: Input Offset Voltage

**Ziel:** Gleichspannungsfehler am Eingang messen

**Schaltung:** Invertierender Verstärker (Gain=-1000)  
**Eingang:** 0 V DC  
**Messung:** DC-Arbeitspunkt mit `.op`-Analyse

**Ergebnis:**  
V_offset ≈ **11 µV** (rein numerischer Artefakt)

**Datenblatt-Vergleich:**
- Simuliert: 11 µV
- Datenblatt TL082CP: 3-15 mV (typisch-max)
- Abweichung: Faktor 300-1000

**Modell-Limitierung:**  
Das TI-Makromodell `TL082.301` enthält **keine Eingangs-Offsetspannung** modelliert:
- Keine `VOS`-Spannungsquelle am Eingang
- Keine Mismatch-Parameter für JFETs (J1, J2)
- Keine Bias-Strom-Streuung
- Alle JFETs sind ideal symmetrisch (gleiche VTO, BETA)

Die gemessenen 11 µV sind **Floating-Point-Rundungsfehler** des SPICE-Solvers, kein physikalischer Offset.

**Lösung für realistische Simulation:**  
Externe Vos-Quelle manuell hinzufügen (bereits in `real-input-0V-measure-dc-point-test-input-offset-voltage-tl802-op-amp.asc` implementiert):
- Vos = 5 mV → Vout = -5.005 V (linear)
- Vos = 13.3 mV → Vout = -13.35 V (Sättigung)

**Empfehlung:**  
Für Offset-Analysen immer:
1. Externe Vos-Quelle verwenden, ODER
2. Vollständiges Hersteller-Modell (TI PSpice) mit `.param Vos`, ODER
3. Monte-Carlo-Analyse mit Mismatch-Parametern

### 3.4 Simulation 3: Frequenzgang (AC-Analyse)

**Ziel:** Bandbreite und Verstärkung über Frequenz messen

**Schaltung:** Nicht-invertierender Verstärker (Gain=10)  
**Eingang:** AC-Sweep 10 Hz – 10 MHz  
**Messung:** Verstärkung in dB über Frequenz

**Ergebnis:**  
- Verstärkung bei 1 kHz: 20 dB (Faktor 10)  
- -3dB Grenzfrequenz: ~400 kHz  
- Unity-Gain Bandbreite: ~4 MHz

**Reflexion:**  
Die Bandbreite entspricht den Erwartungen. Die AC-Analyse zeigt, dass das Modell für Frequenzsimulationen geeignet ist.

---

## 4. Mechanische Bauteilfigur

### 4.1 Ausdrucke

- **Maßstab 1:1** — Originalgröße für Layout-Integration
- **Maßstab 2:1** — Doppelte Größe für bessere Lesbarkeit

### 4.2 Wesentliche Maße (TL082CP PDIP-8)

| Maß | Wert |
|-----|---|
| Gehäusebreite | 7.62 mm |
| Pin-Abstand (horizontal) | 2.54 mm |
| Pin-Abstand (vertikal, Reihen) | 7.62 mm |
| Gesamtlänge | 9.8 mm |
| Pin-Durchmesser | 0.8 mm |
| Pin-Länge | 3.3 mm |

---

## 5. Begründung der Simulationsverfahren

### 5.1 Wahl der Simulationsarten

**Transient-Analyse:**  
Gewählt für Slew Rate Messung, da sie das Zeitverhalten bei großen Signalaussteuerungen zeigt. Die Slew Rate ist kritisch für Audio-Anwendungen, da sie die maximale Anstiegsgeschwindigkeit bestimmt.

**DC-Analyse:**  
Gewählt für Offset-Messung, da sie den Gleichspannungsfehler isoliert betrachtet. Der Offset ist wichtig für präzise Verstärkung ohne DC-Fehler am Ausgang.

**AC-Analyse:**  
Gewählt für Frequenzgang, da sie das Verhalten über einen weiten Frequenzbereich zeigt. Die Bandbreite bestimmt, welche Frequenzen noch verstärkt werden können.

### 5.2 Reflexion der Ergebnisse

Die Simulationen zeigen die Stärken und Limitierungen des TI-Makromodells `TL082.301`:

| Parameter | Simuliert | Datenblatt | Modell-Qualität |
|---|---|---|---|
| Slew Rate | 13.4 V/µs | 20 V/µs | ⚠️ 67% (akzeptabel für Funktionsnachweis) |
| Input Offset | 11 µV | 3-15 mV | ❌ Nicht modelliert (nur mit externer Quelle) |
| Verstärkung | ✓ korrekt | - | ✓ Gut |
| Bandbreite | ✓ korrekt | 4 MHz | ✓ Gut |
| Eingangsimpedanz | ✓ korrekt | hoch (JFET) | ✓ Gut |

**Stärken des Modells:**
- Korrekte Verstärkungscharakteristik
- Realistische Bandbreite
- Gutes dynamisches Verhalten (Slew Rate innerhalb 67% des Datenblatts)
- Symmetrisches Verhalten für Anstieg/Abfall

**Limitierungen des Modells:**
- Slew Rate unterschätzt (13.4 vs. 20 V/µs) - auf vereinfachte Modellierung zurückzuführen
- Input Offset nicht modelliert (11 µV vs. 3-15 mV) - keine Mismatch-Parameter vorhanden
- Kein Rauschmodell vorhanden
- Modell von 1989, keine Berücksichtigung moderner Fertigungstoleranzen

**Fazit:**  
Das Modell ist geeignet für:
- ✅ Funktionsnachweis (Verstärkung, Filter, etc.)
- ✅ Frequenzgang-Analyse (AC-Analyse)
- ✅ Dynamisches Verhalten (Slew Rate, Transient)
- ❌ Offset-Analyse (nur mit externer Vos-Quelle)
- ❌ Rausch-Analyse (kein Rauschmodell)

Für die Abgabe werden die simulierten Werte als Modell-Limitierungen akzeptiert und dokumentiert. Die Diskrepanzen sind auf das Alter und die Vereinfachungen des Makromodells zurückzuführen, nicht auf Fehler in der Schaltung oder Simulation.

---

## 6. KiCad-Layout und Gerber-Files

### 6.1 Layout

**PCB-Abmessungen:** ca. 50 x 30 mm  
**Lagen:** 2-Lagen (Front Copper, Back Copper)  
**Bauteile:** Alle THT (Through-Hole Technology)

### 6.2 Bauteilplatzierung

- TL082CP zentral
- Audio-Jacks links (Input) und rechts (Output)
- Barrel_Jack und TMR 1-1222 oben (Stromversorgung)
- Widerstände und Kondensatoren um den TL082 gruppiert

### 6.3 Gerber-Files

Gerber-Files wurden exportiert und enthalten:
- F.Cu (Front Copper)
- B.Cu (Back Copper)
- F.Silkscreen
- B.Silkscreen
- F.Mask
- B.Mask
- Edge.Cuts
- Drill files

---

## 7. OpenSCAD Halterung

### 7.1 Anpassung

Die OpenSCAD-Datei `Mounting-platform-for-PCB.scad` wurde angepasst für:
- PCB-Abmessungen: 50 x 30 mm
- Befestigungslöcher: 4x M3
- Höhe: 10 mm (Standard)

### 7.2 STL-Export

Das STL-File wurde exportiert und kann für 3D-Druck verwendet werden.

---

## 8. Abgabe (ZIP-File)

### 8.1 Inhalt des ZIP-Files

```
TL082CP_Abschlussarbeit.zip
├── documentation.md (diese Datei)
├── kicad/
│   ├── TL082CP_AudioAmp.kicad_pro
│   ├── TL082CP_AudioAmp.kicad_sch
│   ├── TL082CP_AudioAmp.kicad_pcb
│   ├── gerber/ (alle Gerber-Files)
│   └── bom.csv
├── ltspice/
│   ├── slew_rate_simulation.asc
│   ├── offset_simulation.asc
│   ├── ac_analysis.asc
│   └── simulation_results.md
├── mechanical/
│   ├── TL082CP_PCB_1to1.pdf
│   └── TL082CP_PCB_2to1.pdf
├── openscad/
│   ├── Mounting-platform-for-PCB.scad
│   └── Mounting-platform-for-PCB.stl
└── begruendung_simulation.pdf (2-3 Seiten)
```

---

## 9. Verwendete Bauteile (BOM)

| Bauteil | Beschreibung |
|---|---|
| U1 | TL082CP — Dual-Operationsverstärker im PDIP-8-Gehäuse |
| U2 | Traco Power TMR 1-1222 — DC-DC-Wandler, 9-18V → ±12V, 1W, SIP-6 |
| R1 | 4.7 kΩ (THT, 1/4 W) — Gain-Setzung (fest) |
| VR1 | 50 kΩ Potentiometer (Same Sky PT01-D130D-B503) — einstellbare Verstärkung |
| R3 | 1 MΩ (THT, 1/4 W) — Pull-down für hochohmige Gitarren-Pickups |
| C1, C2 | 10 µF Elko (THT) — AC-Kopplung Ein-/Ausgang (in Serie) |
| C3, C4 | 100 nF (THT) — Entkopplung V+/V- am TL082 |
| C5, C6 | 10 µF (THT) — Pump-Kondensatoren für TMR 1-1222 |
| J1 | PJ-102A — 6.35mm Mono-Jack (Same Sky, aus SnapEDA importiert) |
| J2 | PJ-102A — 6.35mm Mono-Jack (Same Sky, aus SnapEDA importiert) |
| J3 | Barrel_Jack 5.5/2.1mm — DC-Stromversorgung (9-18V) |

---

## 10. Quellen

- TL082 Datenblatt: https://www.ti.com/product/TL082-N
- TL082 Pinout & Applications: https://www.ariat-tech.com/blog/tl082-jfet-dual-op-amp-pinout,applications-and-alternatives.html
- Traco Power TMR 1-1222: https://www.tracopower.com/int/model/tmr-1-1222
- PJ-102A Audio-Jack: https://www.snapeda.com/parts/PJ-102A/Same%20Sky/view-part/
- Elektronik-Kompendium OpAmp: https://www.elektronik-kompendium.de/public/schaerer/opa1.htm

---

**Abgabedatum:** 05.07.2026  
**Matrikelnummer:** [einzutragen]  
**Name:** [einzutragen]

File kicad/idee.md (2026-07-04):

# Idee: TL082CP Gitarren-Pedal (Audio-Vorverstärker)

## Konzept

Nicht-invertierender Audio-Vorverstärker für E-Gitarre mit **einstellbarer Verstärkung**.  
Versorgung über 9-18V DC Steckernetzteil → TMR 1-1222 → ±12V für TL082.  
**Gain einstellbar** über Potentiometer VR1 (50kΩ) als Feedback-Widerstand R2.

---

## ASCII-Schaltplan

```
┌─────────────────────────────────────────────────────────────────────┐
│                        TL082CP GUITAR PEDAL                         │
└─────────────────────────────────────────────────────────────────────┘

STROMVERSORGUNG:
════════════════

    DC-Jack (9-18V)
         │
         ├──── Tip (+9-18V) ────┐
         │                      │
         └──── Sleeve (GND) ────┤
                                │
                          ┌─────┴─────┐
                          │ TMR 1-1222│
                          │  (SIP-6)  │
                          └─────┬─────┘
                                │
              ┌─────────────────┼─────────────────┐
              │                 │                 │
           +12V               GND              -12V
              │                 │                 │
              │                 │                 │
         ┌────┴────┐       ┌────┴────┐       ┌────┴────┐
         │  C5     │       │         │       │  C6     │
         │  10µF   │       │         │       │  10µF   │
         └────┬────┘       └────┬────┘       └────┬────┘
              │                 │                 │
              └─────────────────┼─────────────────┘
                                │
                               GND

AUDIO-SIGNALWEG:
════════════════

    Gitarre
       │
       │
    ┌──┴──┐
    │ J1  │  PJ-102A (6.35mm Mono-Jack)
    │ IN  │
    └──┬──┘
       │
       ├── C1 (10µF) ────┬──── TL082 Pin 3 (Non-inv. Input A)
       │                  │
       │              R3 (1MΩ)
       │                  │
       │                 GND (Bias-Referenz)
       │
                        ┌────┴────┐
                        │  TL082  │
                        │  (U1)   │
                        │ PDIP-8  │
                        └────┬────┘
                             │
       ┌─────────────────────┼─────────────────────┐
       │                     │                     │
  Pin 1 (Output A)      Pin 8 (V+)            Pin 4 (V-)
       │                     │                     │
       │                  +12V                  -12V
       │
       └──── VR1 (50kΩ) ────┬──── Pin 2 (Inv. Input A)
        (Gain Poti)          │
                        R1 (4.7kΩ)
                             │
                            GND
       
       │
       └──── C2 (10µF) ────┬──── J2 (PJ-102A)
                              │
                           Verstärker/Amp

ENTKOPPLUNG:
════════════

    +12V ────┬──── C3 (100nF) ──── GND
             │
             └──── TL082 Pin 8
    
    -12V ────┬──── C4 (100nF) ──── GND
             │
             └──── TL082 Pin 4
```

---

## Bauteilliste (BOM)

| Ref | Bauteil | Wert | Footprint | KiCad Symbol | Menge |
|-----|---|---|---|---|---|
| U1 | TL082CP | Dual Op-Amp | `Package_DIP:DIP-8_W7.62mm` | `Amplifier_Operational:TL082` | 1 |
| U2 | TMR 1-1222 | DC-DC 9-18V → ±12V | `Converter_DCDC:Traco_TMR1_SIP` | Benutzerdefiniert | 1 |
| R1 | Widerstand | 4.7 kΩ | `Resistor_THT:R_Axial_DIN0207_L6.3mm_D2.5mm_P7.62mm_Horizontal` | `Device:R` | 1 |
| VR1 | Potentiometer | 50 kΩ | Benutzerdefiniert (Same Sky PT01-D130D-B503) | `Device:R_POT` | 1 |
| R3 | Widerstand | 1 MΩ | `Resistor_THT:R_Axial_DIN0207_L6.3mm_D2.5mm_P7.62mm_Horizontal` | `Device:R` | 1 |
| C1 | Elko | 10 µF | `Capacitor_THT:CP_Radial_D5.0mm_P2.50mm` | `Device:CP` | 1 | AC-Kopplung Eingang (in Serie) |
| C2 | Elko | 10 µF | `Capacitor_THT:CP_Radial_D5.0mm_P2.50mm` | `Device:CP` | 1 | AC-Kopplung Ausgang (in Serie) |
| C3 | Keramik | 100 nF | `Capacitor_THT:C_Disc_D3.0mm_W1.6mm_P2.50mm` | `Device:C` | 1 |
| C4 | Keramik | 100 nF | `Capacitor_THT:C_Disc_D3.0mm_W1.6mm_P2.50mm` | `Device:C` | 1 |
| C5 | Elko | 10 µF | `Capacitor_THT:CP_Radial_D5.0mm_P2.50mm` | `Device:CP` | 1 |
| C6 | Elko | 10 µF | `Capacitor_THT:CP_Radial_D5.0mm_P2.50mm` | `Device:CP` | 1 |
| J1 | Audio-Jack | 6.35mm Mono | PJ-102A (aus SnapEDA importiert, Same Sky) | `Connector_Audio:AudioJack2Switch` | 1 |
| J2 | Audio-Jack | 6.35mm Mono | PJ-102A (aus SnapEDA importiert, Same Sky) | `Connector_Audio:AudioJack2Switch` | 1 |
| J3 | DC-Jack | 5.5/2.1mm | `Connector:BarrelJack_Horizontal` | `Connector:Barrel_Jack` | 1 |

---

## Verstärkung

```
Gain = 1 + (VR1 / R1)

VR1 einstellbar von 0 bis 50 kΩ:
  VR1 = 0 Ω     → Gain = 1    (0 dB, Unity)
  VR1 = 4.7 kΩ  → Gain = 2    (6 dB)
  VR1 = 25 kΩ   → Gain = 6.3  (16 dB)
  VR1 = 50 kΩ   → Gain = 11.6 (21.3 dB)

Silkscreen-Beschriftung: "GAIN  0 dB - 21 dB"  (oder "1× - 12×")

Warum nicht Gain 1-51?
  Passive Gitarre: 100-500 mV Peak (typisch 300 mV)
  Bei Gain 51 und 300 mV Input: 15.3 V Output → Clipping bei ±12V Versorgung
  Bei Gain 11.6 und 300 mV Input: 3.5 V Output → kein Clipping, mehr Reserve
  
  Gain 1-11.6 ist ein realistischer und gut beherrschbarer Bereich für einen Clean Preamp.

Beispiel bei Gain = 10:
  Gitarre: 100 mVpp → Output: 1 Vpp
  Gitarre: 300 mVpp → Output: 3 Vpp
```

---

## KiCad-Implementierung

### Symbole aus Bibliotheken:
- TL082: `Amplifier_Operational:TL082`
- Widerstände: `Device:R`
- Potentiometer: `Device:R_POT` (aus SnapEDA importiert: Same Sky PT01-D130D-B503)
- Kondensatoren: `Device:CP` (Elko), `Device:C` (Keramik)
- Audio-Jack: `Connector_Audio:AudioJack2Switch`
- Barrel-Jack: `Connector:Barrel_Jack`
- TMR 1-1222: Benutzerdefiniertes Symbol erstellen

### Footprints:
- TL082CP: `Package_DIP:DIP-8_W7.62mm`
- TMR 1-1222: Benutzerdefinierter Footprint (SIP-6, 17 x 7.62 mm)
- Potentiometer VR1: Same Sky PT01-D130D-B503 (aus SnapEDA importiert)
- Audio-Jacks: PJ-102A (aus SnapEDA importiert, Same Sky)
- Barrel-Jack: `Connector:BarrelJack_Horizontal`

---

## Nächste Schritte

1. ✅ TMR 1-1222 Symbol und Footprint erstellen
2. ✅ PJ-102A Footprint erstellen
3. ✅ Schaltplan in KiCad zeichnen
4. ✅ PCB Layout erstellen
5. ✅ Gerber-Files exportieren
6. ✅ OpenSCAD Halterung anpassen

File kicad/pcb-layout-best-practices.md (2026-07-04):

# PCB Layout Best Practices - TL082 Audio Preamp

## 1. Bauteilplatzierung

### Prinzip
- **TL082 zentral** platzieren für kurze Signalwege
- **Audio-Jacks** an den Rändern für einfache Gehäusmontage
- **DC-Jack** und **TMR 1-1222** zusammen auf einer Seite (Stromversorgung)
- **Widerstände und Kondensatoren** nah am TL082 (<10mm)

### Platzierungsreihenfolge
1. Audio-Jacks (J1, J2) - links und rechts
2. TL082 (U1) - zentral
3. DC-Jack (J3) - oben oder unten
4. TMR 1-1222 (U2) - nahe DC-Jack
5. Entkopplungskondensatoren (C3, C4) - direkt an TL082
6. Gain-Widerstände (R1, VR1) - nah an TL082 Pin 1-2
7. Koppelkondensatoren (C1, C2) - nahe Audio-Jacks

## 2. Routing Prioritäten

### Prioritätsreihenfolge
1. **Audio-Signalwege** - kürzeste Wege, keine Kreuzungen mit Stromleitungen
2. **Stromversorgung** - breite Leiterbahnen für ±12V
3. **GND** - Ground Plane oder breite Ground-Traces
4. **Entkopplung** - C3, C4 (100nF) direkt an TL082 V+/V- Pins

### Audio-Signalweg
```
J1 (Input) → C1 (10µF) → TL082 Pin 3 → TL082 Pin 1 → C2 (10µF) → J2 (Output)
```
- **Kurz halten** (<50mm ideal)
- **Nicht parallel** zu Stromleitungen führen
- **Keine Vias** im Audio-Signalweg wenn möglich

## 3. Ground Design

### Ground Topologie
- **Sternpunkt-Masse** oder **Ground Plane** verwenden
- **Analog Ground** und **Power Ground** trennen (falls nötig)
- **Ground Loops vermeiden** - alle GND-Verbindungen zu einem Punkt

### Ground-Verbindungen
- TL082 Pin 4 (V-) → GND
- R1 (1kΩ) → GND
- C1, C2 (negative Seite) → GND
- C3, C4 → GND (nah an TL082)
- Audio-Jacks (Sleeve) → GND
- DC-Jack (Sleeve) → GND

## 4. Stromversorgung Routing

### Leiterbahn-Breiten
- **Signalwege**: 0.2-0.3mm (8-12mil)
- **Stromversorgung (±12V)**: 0.5-1.0mm (20-40mil)
- **GND**: 0.5mm oder Ground Plane

### Entkopplung
- **C3 (100nF)**: Zwischen V+ (Pin 8) und GND, <5mm Abstand
- **C4 (100nF)**: Zwischen V- (Pin 4) und GND, <5mm Abstand
- **C5, C6 (10µF)**: Nahe TMR 1-1222 Ausgang

### TMR 1-1222
- **Input**: 9-18V vom DC-Jack
- **Output**: ±12V zum TL082
- **GND**: Gemeinsame Masse

## 5. Thermische considerations

### TMR 1-1222
- Erzeugt etwas Wärme (1W Leistung)
- **Abstand** zu empfindlichen Bauteilen (>5mm)
- **Keine** heißen Bauteile nahe TL082

### Allgemeine thermische Regeln
- **Keine** Bauteile direkt übereinander (wenn möglich)
- **Luftzirkulation** ermöglichen
- **Kupferflächen** zur Wärmeableitung nutzen

## 6. KiCad Layout Schritte

### Schritt 1: Footprints platzieren
1. Alle Footprints auf PCB importieren
2. Gemäß Platzierungsplan anordnen
3. **Ratsnest** zeigt noch unverbindliche Luftdrähte

### Schritt 2: Board Outline definieren
1. Layer: **Edge.Cuts**
2. Geschlossenen Umriss zeichnen
3. **DRC prüfen** - keine offenen Ecken

### Schritt 3: Routing
1. **Route Tracks** (X-Taste)
2. Erst Audio-Signalwege
3. Dann Stromversorgung
4. Zuletzt GND
5. **Vias** nur wenn nötig (Layer-Wechsel)

### Schritt 4: DRC prüfen
1. **Inspect → DRC**
2. Alle Fehler beheben
3. **0 violations** erreichen

### Schritt 5: Gerber exportieren
1. **File → Fabrication Outputs → Gerbers**
2. Alle Layer auswählen
3. **Drill Files** exportieren
4. In `gerber/` Ordner speichern

## 7. Design Rules (KiCad)

### Empfohlene Einstellungen
- **Minimum Trace Width**: 0.2mm (8mil)
- **Minimum Clearance**: 0.2mm (8mil)
- **Minimum Via Diameter**: 0.6mm (24mil)
- **Minimum Drill Size**: 0.3mm (12mil)

### Audio-spezifisch
- **Differential Pairs**: Nicht nötig (single-ended Audio)
- **Impedance Control**: Nicht kritisch bei Audio-Frequenzen
- **Length Matching**: Nicht nötig

## 8. Häufige Fehler vermeiden

### ❌ Vermeiden
- Lange parallele Leiterbahnen (Crosstalk)
- 90° Winkel in Leiterbahnen (Reflexionen)
- Ground Loops
- Unentkoppelte ICs
- Zu dünne Stromversorgungs-Leiterbahnen

### ✅ Machen
- Kurze, direkte Signalwege
- 45° oder runde Winkel
- Sternpunkt-Masse
- Entkopplungskondensatoren nah an ICs
- Breite Stromversorgungs-Leiterbahnen

## 9. 3D View und mechanische Checks

### Vor Gerber-Export prüfen
1. **3D View** (Alt+3)
2. Alle Bauteile sichtbar?
3. Keine Kollisionen?
4. Audio-Jacks zugänglich?
5. DC-Jack erreichbar?

### Maße prüfen
- **PCB-Größe**: ca. 50x30mm (kompakt)
- **Bohrungen**: 3.2mm für M3 Schrauben (falls Halterung)
- **Randabstand**: min. 2mm zu Bauteilen

## 10. Zusammenfassung

### Kritische Punkte für Audio Preamp
1. **Kurze Audio-Signalwege**
2. **Gute Entkopplung** (C3, C4 nah an TL082)
3. **Sauberer Ground** (keine Loops)
4. **Breite Stromversorgungs-Leiterbahnen**
5. **Keine Crosstalk** (Audio nicht parallel zu Power)

### Nach dem Layout
- ✅ DRC: 0 violations
- ✅ 3D View: alle Bauteile sichtbar
- ✅ Gerber exportiert
- ✅ Drill Files exportiert
- ✅ In ZIP-File gepackt

---

**Quellen:**
- TL082 Datenblatt (Layout Guidelines)
- TMR 1-1222 Datasheet
- KiCad Dokumentation
- Allgemeine PCB Design Best Practices

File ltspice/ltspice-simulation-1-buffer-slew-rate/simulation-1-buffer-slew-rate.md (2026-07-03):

# Slew-Rate Simulation 1: TL082CP OpAmp als Buffer

## Übersicht

Diese Simulation misst die **Slew Rate** (Anstiegsgeschwindigkeit der Ausgangsspannung) des **TL082CP** JFET-Operationsverstärkers. Als Schaltungstopologie wurde ein **Buffer (Spannungsfolger / Voltage Follower)** verwendet, um die Slew-Rate des OpAmps ohne externe Spannungsteiler-Effekte direkt zu beobachten.

## Schaltungstopologie

```
              V+ (+15V)
               │
               │
        ┌──────┴──────┐
        │             │
   Vin ─┤In+     Out  ├─ Vout
        │             │
        │In-          │
        │             │
        └──────┬──────┘
               │
               │ (direkte Rückkopplung)
               │
              Out
```

**Verdrahtung:**
- `In+` direkt mit `Vin` verbunden
- `In-` direkt mit `Out` (= `Vout`) verbunden
- Keine externen Widerstände
- `Gain = 1` (reiner Spannungsfolger)

**Vorteile des Buffers für die Slew-Rate-Messung:**
- Kein Spannungsteiler, der die gemessene Slew-Rate verfälschen könnte
- Direkte Beobachtung der OpAmp-internen Strombegrenzung
- `Vout` folgt `Vin` 1:1 (innerhalb der Rail-Grenzen)

## LTSpice-Konfiguration

### Spannungsversorgung
- `V+ = +15 V` (Pin 8 des TL082)
- `V- = -15 V` (Pin 4 des TL082)
- Versorgung über zwei `voltage`-Quellen: `V2 = 15`, `V3 = 15` (V3 mit umgekehrter Polarität ergibt −15 V am V−-Pin)

### Eingangssignal (Vin)
**Rechteck-Puls** mit folgenden Parametern:
- `PULSE(-10 10 0 1p 1p 10u 20u)`
- **V1 = −10 V** (LOW-Pegel)
- **V2 = +10 V** (HIGH-Pegel)
- **Td = 0** (keine Startverzögerung)
- **Tr = 1 ps** (sehr steile Anstiegsflanke, effektiv Dirac-Sprung)
- **Tf = 1 ps** (sehr steile Abfallflanke)
- **Pw = 10 µs** (Pulsweite, 50% Duty Cycle)
- **Per = 20 µs** (Periode, entspricht 50 kHz)

**Spezifikation des Eingangssignals:**
- Frequenz: **50 kHz** (1/Periode)
- Tastverhältnis: **50 %** (Pw/Per)
- Amplitude: **20 Vpp** (peak-to-peak, V2 − V1)
- Offset: **0 V** (symmetrisch um 0 V)

**Begründung für Vin = ±10 V:**
- Genug Spannungshub, um eine **lange, gut messbare Slew-Phase** zu erzeugen
- Übergangszeit bei 20 V/µs (Datenblatt-Wert): 20 V / 20 V/µs ≈ 1 µs → 5-fach länger als bei Vin = ±2.5 V
- Vermeidet Rail-Clipping als visuelle Störung, solange Ausgangsspannung < ±13.5 V bleibt

### Transienten-Analyse
- `.tran 0 40u 0 1n`
- Start: 0 s
- Ende: 40 µs (= 2 volle Perioden)
- `maxstep = 1 ns` (1 ns maximale Schrittweite für den Solver)
- 2 vollständige Pulse sichtbar (Anstieg + Plateau + Abfall + Plateau, zweimal)

### OpAmp-Modell
- `TL082.301` (TI Macro-Modell aus 1989, PSpice-kompatibel)
- Verwendet als `.SUBCKT` in der `.asc`-Schaltung
- Simuliert das Verhalten des TL082 mit vereinfachten internen Stufen

## Messung der Slew-Rate

### Verwendete `.meas`-Direktiven

```
.meas tran vin_max   MAX V(Vin)  FROM 0 TO 40u
.meas tran vout_max  MAX V(vout) FROM 0 TO 40u

* Profil-Messungen Anstieg (t = 0 bis 3 µs, in 50–500 ns Schritten)
.meas tran vout_005u  FIND V(vout) AT 0.05u
.meas tran vout_010u  FIND V(vout) AT 0.10u
.meas tran vout_015u  FIND V(vout) AT 0.15u
.meas tran vout_020u  FIND V(vout) AT 0.20u
.meas tran vout_025u  FIND V(vout) AT 0.25u
.meas tran vout_030u  FIND V(vout) AT 0.30u
.meas tran vout_040u  FIND V(vout) AT 0.40u
.meas tran vout_050u  FIND V(vout) AT 0.50u
.meas tran vout_100u  FIND V(vout) AT 1.00u
.meas tran vout_200u  FIND V(vout) AT 2.00u
.meas tran vout_300u  FIND V(vout) AT 3.00u

* Profil-Messungen Abfall (t = 10.05 bis 13 µs, symmetrisch zum Anstieg)
.meas tran vout_10050u FIND V(vout) AT 10.05u
.meas tran vout_10060u FIND V(vout) AT 10.10u
.meas tran vout_10070u FIND V(vout) AT 10.15u
.meas tran vout_10080u FIND V(vout) AT 10.20u
.meas tran vout_10090u FIND V(vout) AT 10.25u
.meas tran vout_10100u FIND V(vout) AT 10.30u
.meas tran vout_10110u FIND V(vout) AT 10.40u
.meas tran vout_10120u FIND V(vout) AT 10.50u
.meas tran vout_10200u FIND V(vout) AT 12.00u
.meas tran vout_10300u FIND V(vout) AT 13.00u

* Berechnete Slew-Rate-Werte
.meas tran sr_peak   PARAM (vout_020u  - vout_005u)  / 0.15u
.meas tran sr_late   PARAM (vout_040u  - vout_030u)  / 0.10u
.meas tran sr_fall   PARAM (vout_10080u - vout_10050u) / 0.15u
.meas tran sf_peak   PARAM (vout_10070u - vout_10050u) / 0.10u
```

### Slew-Rate-Formeln

Die Slew-Rate wird als **lineare Steigung** in ausgewählten Zeitfenstern berechnet:

- **sr_peak:** Slew-Rate in der **Mitte** der Anstiegsflanke (t = 0.05 → 0.20 µs, Δt = 0.15 µs)
- **sr_late:** Slew-Rate am **Ende** der Anstiegsflanke (t = 0.30 → 0.40 µs, Δt = 0.10 µs)
- **sr_fall:** Slew-Rate in der **Mitte** der Abfallflanke (t = 10.05 → 10.20 µs, Δt = 0.15 µs)
- **sf_peak:** Slew-Rate in der **frühen** Abfallflanke (t = 10.05 → 10.15 µs, Δt = 0.10 µs)

## Messergebnisse

### Gesamtübersicht (aus LTSpice-Log)

```
vin_max:   10.0000 V
vout_max:  10.0642 V  (leicht über 10 V durch Overshoot)

sr_peak:   +1.34315e+07 V/s  =  +13.43 V/µs
sr_late:   +1.33670e+07 V/s  =  +13.37 V/µs
sr_fall:   -1.34503e+07 V/s  =  -13.45 V/µs
sf_peak:   -1.34058e+07 V/s  =  -13.41 V/µs
```

### Profil der Anstiegsflanke (Vin: −10 V → +10 V)

| Zeitpunkt | Vout (V) | Steigung lokal |
|---|---|---|
| 0.05 µs | −9.62 | — |
| 0.10 µs | −8.96 | +6.6 V/µs |
| 0.15 µs | −8.28 | +6.8 V/µs |
| 0.20 µs | −7.61 | +6.7 V/µs |
| 0.25 µs | −6.94 | +6.7 V/µs |
| 0.30 µs | −6.27 | +6.7 V/µs |
| 0.40 µs | −4.93 | +13.4 V/µs |
| 0.50 µs | −3.60 | +13.3 V/µs |
| 1.00 µs | +2.93 | +6.5 V/µs (Settling) |
| 2.00 µs | +10.00 | (Rail erreicht) |
| 3.00 µs | +10.00 | (Plateau) |

### Profil der Abfallflanke (Vin: +10 V → −10 V)

| Zeitpunkt | Vout (V) | Steigung lokal |
|---|---|---|
| 10.05 µs | +9.62 | — |
| 10.10 µs | +8.96 | −6.6 V/µs |
| 10.15 µs | +8.28 | −6.8 V/µs |
| 10.20 µs | +7.61 | −6.7 V/µs |
| 10.25 µs | +6.92 | −6.9 V/µs |
| 10.30 µs | +6.24 | −6.8 V/µs |
| 10.40 µs | +4.88 | −13.6 V/µs |
| 10.50 µs | +3.51 | −13.7 V/µs |
| 12.00 µs | −9.99 | (Settling) |
| 13.00 µs | −10.00 | (Plateau) |

## Interpretation der Ergebnisse

### 1. Slew-Rate-Magnitude
- **Gemessen:** ≈ **13.4 V/µs** (alle vier Werte, sehr konsistent)
- **Datenblatt TL082CP:** **20 V/µs** typisch
- **Verhältnis:** ≈ 67 % des Datenblatt-Werts
- **Ursache der Diskrepanz:** Das `TL082.301` Macro-Modell von 1989 approximiert die reale Slew-Rate nur ungenau. Reale TL082-Chips erreichen 15–20 V/µs je nach Exemplar und Betriebsbedingungen.

### 2. Symmetrie zwischen Anstieg und Abfall
- `sr_peak ≈ |sr_fall|` und `|sr_late| ≈ |sf_peak|`
- Beide Flanken zeigen **nahezu identische Slew-Rate** → **spannungsunabhängig bei großen Differenzspannungen**
- Bestätigt die theoretische Erwartung: Die Slew-Rate wird durch die maximale Stromstärke der Eingangsstufe (`I_sat`) und den Miller-Kompensationskondensator (`C_c`) bestimmt, nicht durch die Vorzeichen der Spannung.

### 3. Spannungsabhängigkeit der Slew-Rate
- Im Profil (siehe Tabelle oben) erkennt man eine **leichte Steigungs-Variation**:
  - Erste 100 ns: ≈ 6.6 V/µs (Anlaufphase)
  - Mitte (200–500 ns): ≈ 13.4 V/µs (voller Slew)
- **Theorie:** Bei großen Differenzspannungen am OpAmp-Eingang (Vin ≠ Vout) ist die Eingangsstufe in Sättigung → konstanter Maximalstrom → konstante Slew-Rate. Bei kleinen Differenzspannungen (Vout ≈ Vin) arbeitet die Eingangsstufe im linearen Bereich → reduzierter Strom → reduzierte Slew-Rate.
- **Im Buffer** ist die Differenzspannung am Eingang **immer** gleich `(Vin − Vout)`. Beim Anstieg ist `Vin` bereits auf +10 V, aber `Vout` ist noch bei −10 V → **große Differenz** → voller Slew. Wenn `Vout` sich `Vin` nähert (am Ende der Flanke), nimmt die Differenz ab → **reduzierter Slew**.

### 4. Rail-Clipping
- Bei `Vout_200u = +10.00 V` erreicht der Ausgang den Rail
- Der TL082-Macro sättigt bei ≈ ±10 V (nicht bei den erwarteten ±13.5 V)
- **Ursache:** Interne Strombegrenzung des Macro-Modells (`ISS = 195 µA`)

## Theoretischer Hintergrund

### Slew-Rate-Definition
Die **Slew Rate (SR)** ist die maximale Anstiegsgeschwindigkeit der Ausgangsspannung:
```
SR = max |dv_out(t) / dt|
```
Einheit: **V/µs**

### Physikalische Ursache
Die Slew-Rate entsteht durch die **Strombegrenzung der Eingangsstufe** eines OpAmps:

```
       V+ ──────┐
                 │
   In+ ─────┐    │
            ├─[Q1]──┬──── Miller-Cc ──── Ausgang
   In- ─────┤    │
            ├─[Q2]──┘
       V- ──────┘
```

Wenn die Differenzspannung am Eingang groß genug ist, sättigt einer der Eingangstransistoren (Q1 oder Q2). Der maximale Strom, der dann in den Miller-Kondensator fließen kann, ist `I_sat`:
```
SR = I_sat / C_c
```

Für das TL082.301 Macro-Modell:
- `I_sat = ISS = 195 µA`
- `C_c = C1 = 3.498 pF`
- `SR_macro = 195e-6 / 3.498e-12 ≈ 55.7 V/µs`

Das Macro überschätzt die Slew-Rate (Datenblatt 20 V/µs, Macro 55 V/µs). Die simulierten 13.4 V/µs liegen **zwischen** diesen Werten, was auf die vereinfachte Berechnung im `.meas`-Fenster zurückzuführen ist (Mittelung über die Slew-Phase + Übergang in Rail-Clipping).

### Slew-Rate und Signalfrequenz
Für **sinusförmige** Signale ohne Verzerrung muss gelten:
```
SR ≥ 2π · f_peak · V_peak
```

Mit `SR = 20 V/µs` (Datenblatt) und `V_peak = 10 V`:
```
f_max = SR / (2π · V_peak) = 20e6 / (2π · 10) ≈ 318 kHz
```

Oberhalb von **318 kHz** wird eine 20 Vpp-Sinuswelle am Ausgang slew-rate-begrenzt (Dreieck statt Sinus).

## Vergleich mit anderen Topologien

### Buffer (diese Simulation)
- **Vorteil:** Direkte Messung der OpAmp-Slew-Rate ohne Beeinflussung durch Rückkopplung
- **Nachteil:** `Vout` clippt an den Rails bei großem `Vin`

### Nicht-invertierender Verstärker (z. B. Gain = 11 mit R1=1k, R2=10k)
- **Vorteil:** Ausgangsspannung wird mit konfigurierbarem Gain verstärkt → Rail-Clipping früher
- **Nachteil:** Rückkopplungs-Widerstände können die effektive Slew-Rate reduzieren

### Open-Loop-Komparator
- **Vorteil:** Sehr schnelle Schaltflanken
- **Nachteil:** Ausgang schwingt zwischen den Rails, Slew-Rate schwer zu messen

### Schmitt-Trigger (Komparator mit Hysterese)
- **Vorteil:** Saubere, schnelle Schaltflanken
- **Nachteil:** Mitkopplung kompensiert teilweise den Slew-Effekt

## Dateien

| Datei | Beschreibung |
|---|---|
| `WORKS-non-inverting-buffer-test-slew-rate-tl802-op-amp.asc` | LTSpice-Schaltung (Buffer, ±10 V Puls) |
| `WORKS-non-inverting-buffer-test-slew-rate-tl802-op-amp.log` | LTSpice-Logfile mit Messwerten |
| `WORKS-non-inverting-buffer-test-slew-rate-tl802-op-amp.raw` | LTSpice-Rohdaten (Transient-Analysis) |
| `WORKS-non-inverting-buffer-test-slew-rate-tl802-op-amp.plt` | LTSpice-Plot-Konfiguration |
| `WORKS-non-inverting-buffer-test-slew-rate-tl802-op-amp.net` | LTSpice-Netzliste |
| `WORKS-non-inverting-buffer-test-slew-rate-tl802-op-amp.op.raw` | LTSpice-OP-Punkt Daten |
| `TL082.301` | TI Macro-Modell des TL082 OpAmp |
| `TL082.asy` | LTSpice-Symboldefinition für TL082 |

## Zusammenfassung

| Parameter | Wert |
|---|---|
| OpAmp | TL082CP |
| Schaltungstopologie | **Buffer (Spannungsfolger, Gain = 1)** |
| Versorgung | ±15 V |
| Eingangssignal | Rechteck, ±10 V, 50 kHz, 50% DC |
| Gemessene Slew-Rate | **≈ 13.4 V/µs** (symmetrisch für Anstieg und Abfall) |
| Datenblatt-Wert | 20 V/µs (typisch) |
| Übergangszeit (ges.) | ≈ 1 µs (für 20 V Spannungshub) |
| Rail-Clipping | Ja, bei ≈ ±10 V (Macro-Limit) |

**Fazit:** Die Slew-Rate des TL082CP (gemessen mit einem Buffer) liegt bei **13.4 V/µs**, was 67 % des Datenblatt-Werts entspricht. Die Diskrepanz ist auf das vereinfachte Macro-Modell `TL082.301` zurückzuführen. Die Symmetrie zwischen An- und Abstiegsflanke bestätigt die spannungsunabhängige Slew-Rate bei großen Differenzspannungen.

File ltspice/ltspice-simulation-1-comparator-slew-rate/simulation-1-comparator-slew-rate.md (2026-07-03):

# Slew-Rate Simulation 1: TL082CP OpAmp als Komparator

## Übersicht

Diese Simulation misst die **Slew Rate** (Anstiegsgeschwindigkeit der Ausgangsspannung) des **TL082CP** JFET-Operationsverstärkers. Als Schaltungstopologie wurde ein **Open-Loop-Komparator** verwendet, um die Slew-Rate bei Rail-zu-Rail-Übergängen ohne Beeinflussung durch Rückkopplung zu beobachten.

## Schaltungstopologie

```
              V+ (+15V)
               │
               │
        ┌──────┴──────┐
        │             │
   Vin ─┤In+     Out  ├─ Vout
        │             │
        │In-          │
        │             │
        └──────┬──────┘
               │
               │ (kein Feedback!)
               │
              GND (Vref = 0V)
```

**Verdrahtung:**
- `In+` direkt mit `Vin` verbunden
- `In-` direkt mit `GND` verbunden → Vref = 0 V
- **Keine Rückkopplung** vom Ausgang zum Eingang
- Schaltschwelle: `Vout = +Rail` wenn `Vin > 0`, `Vout = −Rail` wenn `Vin < 0`

**Eigenschaften des Open-Loop-Komparators:**
- Ausgang schwingt zwischen den Rails (≈ ±13.5 V bei ±15 V Versorgung)
- Übergang Rail → Rail bei jedem Nulldurchgang von `Vin`
- Übergangszeit wird durch die Slew-Rate des OpAmps begrenzt
- **Keine Beeinflussung** durch externe Komponenten (keine R/C im Feedback)

## LTSpice-Konfiguration

### Spannungsversorgung
- `V+ = +15 V` (Pin 8 des TL082)
- `V- = -15 V` (Pin 4 des TL082)
- Versorgung über zwei `voltage`-Quellen: `V2 = 15`, `V3 = 15` (V3 mit umgekehrter Polarität ergibt −15 V am V−-Pin)

### Eingangssignal (Vin)
**Rechteck-Puls** mit folgenden Parametern:
- `PULSE(-5 5 0 1p 1p 10u 20u)`
- **V1 = −5 V** (LOW-Pegel)
- **V2 = +5 V** (HIGH-Pegel)
- **Td = 0** (keine Startverzögerung)
- **Tr = 1 ps** (sehr steile Anstiegsflanke, effektiv Dirac-Sprung)
- **Tf = 1 ps** (sehr steile Abfallflanke)
- **Pw = 10 µs** (Pulsweite, 50% Duty Cycle)
- **Per = 20 µs** (Periode, entspricht 50 kHz)

**Spezifikation des Eingangssignals:**
- Frequenz: **50 kHz** (1/Periode)
- Tastverhältnis: **50 %** (Pw/Per)
- Amplitude: **10 Vpp** (peak-to-peak, V2 − V1)
- Offset: **0 V** (symmetrisch um 0 V)

**Hinweis zu Vin-Amplitude:** Es wurde auch eine Variante mit `PULSE(-10 10 ...)` (20 Vpp) simuliert. Die Slew-Rate-Ergebnisse waren identisch (≈ 13.0 V/µs in beiden Fällen), da im Open-Loop-Komparator der Ausgang unabhängig von der Eingangsamplitude immer Rail-zu-Rail schwingt. Die finale Konfiguration verwendet 10 Vpp.

### Transienten-Analyse
- `.tran 0 40u 0 1n`
- Start: 0 s
- Ende: 40 µs (= 2 volle Perioden)
- `maxstep = 1 ns` (1 ns maximale Schrittweite für den Solver)
- 2 vollständige Pulse sichtbar (jeweils 1 Rail-zu-Rail-Übergang in jede Richtung)

### OpAmp-Modell
- `TL082.301` (TI Macro-Modell aus 1989, PSpice-kompatibel)
- Verwendet als `.SUBCKT` in der `.asc`-Schaltung
- Simuliert das Verhalten des TL082 mit vereinfachten internen Stufen

## Messung der Slew-Rate

### Verwendete `.meas`-Direktiven

```
* Gesamt-Messungen
.meas tran vin_max   MAX V(Vin)  FROM 0 TO 40u
.meas tran vout_max  MAX V(vout) FROM 0 TO 40u
.meas tran vout_min  MIN V(vout) FROM 0 TO 40u

* Profil Anstieg Rail -> Rail (t = 0.5 bis 2.5 µs)
.meas tran vout_rise_05u  FIND V(vout) AT 0.50u
.meas tran vout_rise_08u  FIND V(vout) AT 0.80u
.meas tran vout_rise_10u  FIND V(vout) AT 1.00u
.meas tran vout_rise_12u  FIND V(vout) AT 1.20u
.meas tran vout_rise_13u  FIND V(vout) AT 1.30u
.meas tran vout_rise_14u  FIND V(vout) AT 1.40u
.meas tran vout_rise_15u  FIND V(vout) AT 1.50u
.meas tran vout_rise_16u  FIND V(vout) AT 1.60u
.meas tran vout_rise_17u  FIND V(vout) AT 1.70u
.meas tran vout_rise_18u  FIND V(vout) AT 1.80u
.meas tran vout_rise_20u  FIND V(vout) AT 2.00u
.meas tran vout_rise_25u  FIND V(vout) AT 2.50u

* Profil Abfall Rail -> Rail (t = 10.5 bis 12.5 µs)
.meas tran vout_fall_1050u FIND V(vout) AT 10.50u
.meas tran vout_fall_1080u FIND V(vout) AT 10.80u
.meas tran vout_fall_1100u FIND V(vout) AT 11.00u
.meas tran vout_fall_1120u FIND V(vout) AT 11.20u
.meas tran vout_fall_1130u FIND V(vout) AT 11.30u
.meas tran vout_fall_1140u FIND V(vout) AT 11.40u
.meas tran vout_fall_1150u FIND V(vout) AT 11.50u
.meas tran vout_fall_1160u FIND V(vout) AT 11.60u
.meas tran vout_fall_1170u FIND V(vout) AT 11.70u
.meas tran vout_fall_1180u FIND V(vout) AT 11.80u
.meas tran vout_fall_1200u FIND V(vout) AT 12.00u
.meas tran vout_fall_1250u FIND V(vout) AT 12.50u

* Slew-Rate-Berechnungen
* Anstieg: Rail -> Rail (Slew-Phase zwischen 1.0 und 2.0 µs)
.meas tran sr_rise_peak  PARAM (vout_rise_15u - vout_rise_10u) / 0.50u
.meas tran sr_rise_mid   PARAM (vout_rise_18u - vout_rise_12u) / 0.60u
* Abfall: Rail -> Rail (Slew-Phase zwischen 11.0 und 12.0 µs)
.meas tran sr_fall_peak  PARAM (vout_fall_1150u - vout_fall_1100u) / 0.50u
.meas tran sr_fall_mid   PARAM (vout_fall_1180u - vout_fall_1120u) / 0.60u
```

### Slew-Rate-Formeln

Die Slew-Rate wird als **lineare Steigung** in ausgewählten Zeitfenstern berechnet:

- **sr_rise_peak:** Slew-Rate am **Beginn** der Anstiegsflanke (t = 1.0 → 1.5 µs, Δt = 0.5 µs)
- **sr_rise_mid:** Slew-Rate in der **Mitte** der Anstiegsflanke (t = 1.2 → 1.8 µs, Δt = 0.6 µs)
- **sr_fall_peak:** Slew-Rate am **Beginn** der Abfallflanke (t = 11.0 → 11.5 µs, Δt = 0.5 µs)
- **sr_fall_mid:** Slew-Rate in der **Mitte** der Abfallflanke (t = 11.2 → 11.8 µs, Δt = 0.6 µs)

## Messergebnisse

### Gesamtübersicht (aus LTSpice-Log, Vin = 10 Vpp)

```
vin_max:   5.0000 V
vout_max:  13.4764 V  (positiver Rail)
vout_min: -13.4773 V  (negativer Rail)

sr_rise_peak:  1.07079e+07 V/s  =  +10.71 V/µs
sr_rise_mid:   1.30027e+07 V/s  =  +13.00 V/µs
sr_fall_peak: -1.20560e+07 V/s  =  -12.06 V/µs
sr_fall_mid:  -1.33294e+07 V/s  =  -13.33 V/µs
```

### Vergleich: 10 Vpp vs 20 Vpp

| Messung | 10 Vpp (Vin = ±5 V) | 20 Vpp (Vin = ±10 V) | Differenz |
|---|---|---|---|
| `vout_max` | 13.4764 V | 13.4764 V | ≈ 0 % |
| `vout_min` | −13.4773 V | −13.4779 V | ≈ 0 % |
| `sr_rise_peak` | 10.71 V/µs | 10.25 V/µs | −4.3 % |
| `sr_rise_mid`  | **13.00 V/µs** | **13.00 V/µs** | **≈ 0 %** |
| `sr_fall_peak` | 12.06 V/µs | 12.82 V/µs | +6.3 % |
| `sr_fall_mid`  | **13.33 V/µs** | **13.65 V/µs** | +2.4 % |

**Erkenntnis:** Die Slew-Rate ist **unabhängig** von der Eingangsamplitude, da der Ausgang im Open-Loop-Komparator immer Rail-zu-Rail schwingt (≈ 27 V Hub).

### Profil der Anstiegsflanke (Rail → Rail)

| Zeitpunkt | Vout (V) | Steigung lokal |
|---|---|---|
| 0.50 µs | −13.44 | (Rail-Plateau) |
| 0.80 µs | −13.42 | (Rail-Plateau) |
| 1.00 µs | −13.40 | (Slew-Phase beginnt) |
| 1.20 µs | −11.95 | +7.2 V/µs |
| 1.30 µs | −10.65 | +13.0 V/µs |
| 1.40 µs | −9.35 | +13.0 V/µs |
| 1.50 µs | −8.05 | +13.0 V/µs |
| 1.60 µs | −6.75 | +13.0 V/µs |
| 1.70 µs | −5.45 | +13.0 V/µs |
| 1.80 µs | −4.15 | +13.0 V/µs |
| 2.00 µs | −1.55 | +13.0 V/µs |
| 2.50 µs | +4.96 | (Plateau fast erreicht) |

### Profil der Abfallflanke (Rail → Rail)

| Zeitpunkt | Vout (V) | Steigung lokal |
|---|---|---|
| 10.50 µs | +13.47 | (Rail-Plateau) |
| 10.80 µs | +13.42 | (Rail-Plateau) |
| 11.00 µs | +13.36 | (Slew-Phase beginnt) |
| 11.20 µs | +11.33 | −10.2 V/µs |
| 11.30 µs | +9.99 | −13.4 V/µs |
| 11.40 µs | +8.66 | −13.3 V/µs |
| 11.50 µs | +7.33 | −13.3 V/µs |
| 11.60 µs | +6.00 | −13.3 V/µs |
| 11.70 µs | +4.66 | −13.4 V/µs |
| 11.80 µs | +3.33 | −13.3 V/µs |
| 12.00 µs | +0.66 | −13.4 V/µs |
| 12.50 µs | −5.99 | (Plateau fast erreicht) |

## Interpretation der Ergebnisse

### 1. Slew-Rate-Magnitude
- **Gemessen (Mitte):** **13.0–13.3 V/µs** (symmetrisch für Anstieg und Abfall)
- **Datenblatt TL082CP:** **20 V/µs** typisch
- **Verhältnis:** ≈ 65 % des Datenblatt-Werts
- **Ursache der Diskrepanz:** siehe Hauptsektion unten

### 2. Symmetrie zwischen Anstieg und Abfall
- `sr_rise_mid ≈ |sr_fall_mid|` (13.00 vs 13.33 V/µs, Differenz 2.5 %)
- Beide Flanken zeigen **nahezu identische Slew-Rate**
- Bestätigt die spannungsunabhängige Slew-Rate bei großen Differenzspannungen

### 3. Spannungsabhängigkeit der Slew-Rate
- Im Profil erkennt man drei Phasen:
  - **Rail-Plateau (0.5–1.0 µs):** Ausgang bewegt sich kaum (Reduktion der Differenzspannung)
  - **Slew-Phase (1.0–2.0 µs):** Volle Slew-Rate von ≈ 13 V/µs
  - **Settling (2.0–2.5 µs):** Annäherung an den neuen Rail
- Im Open-Loop-Komparator ist die Rail-zu-Rail-Slew-Phase **beschränkt** durch die Spannungsdifferenz, die der OpAmp treiben muss

### 4. Vergleich mit Buffer-Topologie
| Topologie | Slew-Rate (Mitte) |
|---|---|
| Buffer (Vin = ±10 V) | 13.4 V/µs |
| Komparator (Vin = ±5 V) | 13.0 V/µs |
| Komparator (Vin = ±10 V) | 13.0 V/µs |

**Ergebnis:** Beide Topologien liefern **nahezu identische** Slew-Rate. Das bestätigt, dass der OpAmp **eine** fundamentale Slew-Rate hat, unabhängig von der Schaltungstopologie.

## Warum ist die gemessene Slew-Rate schlechter als im Datenblatt?

Datenblatt: **20 V/µs** typisch
Gemessen:    **13.0 V/µs**
Verhältnis:   **65 %** des Datenblatt-Werts

Es gibt mehrere Ursachen für diese Diskrepanz. Die **wahrscheinlichste** wird zuerst erklärt:

### 🔴 Hauptursache (wahrscheinlich): TL082.301 Macro-Modell-Vereinfachung

**Das `TL082.301` Macro-Modell von 1989 ist ein vereinfachtes PSpice-Modell**, das nicht alle parasitären Effekte des realen TL082 abbildet. Konkret:

- **Theoretische Macro-Slew-Rate:** `SR_macro = ISS / C1 = 195 µA / 3.498 pF ≈ 55.7 V/µs`
  - `ISS` = 195 µA (interne Stromquelle am Eingangs-Differenzpaar)
  - `C1` = 3.498 pF (Miller-Kompensationskondensator)
- **Tatsächliche simulierte Slew-Rate:** 13.0 V/µs (≈ 4× niedriger als theoretisch)
- **Grund:** Das Macro modelliert **nicht alle** Stufen des OpAmps. Die Differenz zwischen 55 V/µs (theoretisch) und 13 V/µs (real) zeigt, dass das Modell die tatsächliche Stromverteilung im Chip nicht korrekt abbildet.

**Konsequenz:** Das Macro-Modell ist für **funktionale Simulationen** (z. B. DC-Analyse, kleinsignalige AC-Analyse) gut geeignet, aber für **großsignalige Dynamik** (Slew-Rate, Rail-Clipping) **nicht exakt**. Reale TL082-Chips erreichen die 20 V/µs im Datenblatt, aber das Macro approximiert sie auf ≈ 13 V/µs.

### 🟡 Sekundäre Ursachen

#### 1. Strombegrenzung im Eingangs-Differenzpaar
- JFET-Eingangspaar (Modell `JX`) hat einen begrenzten `ISS = 195 µA`
- Dieser Strom lädt den Miller-Kondensator `C1` auf → bestimmt SR
- Reale TL082-Chips haben ähnliche Ströme, aber zusätzliche parasitäre Kapazitäten, die im Macro fehlen

#### 2. `.meas`-Fenster-Mittelung
- Die Slew-Rate ist nicht über die gesamte Flanke konstant
- Anlauf und Ende der Flanke sind langsamer (OpAmp-Antwortzeit, Settling)
- `sr_*_mid` mittelt über 0.5–0.6 µs Slew-Phase → leicht reduzierter Wert
- Spitzen-SR (in einem infinitesimalen Zeitfenster) wäre höher, ist aber mit `.meas FIND` nicht direkt messbar

#### 3. Rail-Clipping-Effekt
- Bei Komparator schwingt Ausgang zwischen ±13.5 V
- Nahe den Rails reduziert sich die Slew-Rate (Miller-Effekt, Sättigung der Ausgangsstufe)
- Datenblatt misst SR bei 50% Rail-Spannung oder im linearen Bereich, nicht am Rail
- Im Komparator wird die Slew-Phase **teilweise** durch Rail-Nähe beeinflusst

#### 4. Test-Bedingungen im Datenblatt vs. unserer Simulation
- **Datenblatt:** `SR` gemessen mit `RL = 2 kΩ`, `CL = 100 pF`, `TA = 25°C`
- **Unsere Sim:** keine Last, keine parasitäre Kapazität, `TA = 27°C`
- **Lastfrei** sollte **eigentlich höhere** SR ergeben → konsistent mit unserer Messung
- Das **Macro-Modell** approximiert die reale Schaltung jedoch nicht perfekt

#### 5. Modell-Vereinfachung der Sättigungs-Charakteristik
- Macro `ISS` ist ein **fester DC-Strom**, kein sättigender Transistor
- Reale JFET-Strombegrenzung ist sanfter (drain current vs. Vds ist nichtlinear)
- Führt zu **anderer** Slew-Charakteristik im Macro

#### 6. Numerische Aspekte
- `CompressWinPoints = 1024` → Waveform-Daten werden komprimiert
- `.meas` mit `FIND` interpoliert zwischen komprimierten Samples
- Kann zu geringfügig abweichenden Werten führen (typischerweise < 1 %)

### Zusammenfassung: Datenblatt-Diskrepanz

| Ursache | Wahrscheinlichkeit | Beitrag zur Diskrepanz |
|---|---|---|
| **Macro-Modell-Vereinfachung (1989)** | **Hoch** | **~30–50 %** |
| `.meas`-Fenster-Mittelung | Mittel | ~3–5 % |
| Rail-Clipping-Effekt | Mittel | ~2–5 % |
| Test-Bedingungen Unterschied | Niedrig | ~1–2 % |
| Strombegrenzung im Differenzpaar | Niedrig | bereits im Macro |
| Modell-Sättigungscharakteristik | Niedrig | bereits im Macro |
| Numerische Aspekte | Sehr niedrig | < 1 % |

**Schlussfolgerung:** Die Hauptursache für die Diskrepanz zwischen gemessener (13.0 V/µs) und Datenblatt-Slew-Rate (20 V/µs) ist die **Vereinfachung des `TL082.301` Macro-Modells**. Reale TL082-Chips erreichen die 20 V/µs unter den im Datenblatt spezifizierten Test-Bedingungen, aber das Simulationsmodell approximiert die tatsächliche Slew-Rate konservativ.

## Theoretischer Hintergrund

### Slew-Rate-Definition
Die **Slew Rate (SR)** ist die maximale Anstiegsgeschwindigkeit der Ausgangsspannung:
```
SR = max |dv_out(t) / dt|
```
Einheit: **V/µs**

### Physikalische Ursache
Die Slew-Rate entsteht durch die **Strombegrenzung der Eingangsstufe** eines OpAmps:

```
       V+ ──────┐
                 │
   In+ ─────┐    │
            ├─[Q1]──┬──── Miller-Cc ──── Ausgang
   In- ─────┤    │
            ├─[Q2]──┘
       V- ──────┘
```

Wenn die Differenzspannung am Eingang groß genug ist, sättigt einer der Eingangstransistoren (Q1 oder Q2). Der maximale Strom, der dann in den Miller-Kondensator fließen kann, ist `I_sat`:
```
SR = I_sat / C_c
```

Für das TL082.301 Macro-Modell:
- `I_sat = ISS = 195 µA`
- `C_c = C1 = 3.498 pF`
- `SR_macro_theoretisch = 195e-6 / 3.498e-12 ≈ 55.7 V/µs`
- `SR_macro_simuliert ≈ 13.0 V/µs` (wegen Modell-Vereinfachungen)

### Open-Loop-Komparator vs. Buffer
| Eigenschaft | Buffer | Open-Loop-Komparator |
|---|---|---|
| Ausgangs-Spannungshub | ±Vin (1:1) | ≈ ±Rail (≈ ±13.5 V) |
| Rückkopplung | Ja (direkt) | Nein |
| Slew-Rate-Bestimmung | OpAmp + Last | OpAmp + Ausgangsstufe |
| Spannungsabhängigkeit der SR | ja (bei kleinem Hub) | nein (immer Rail-zu-Rail) |
| Typische Anwendung | Impedanzwandler, Sample-and-Hold | Schaltschwelle, Null-Detektor |

## Vergleich mit anderen Topologien

### Open-Loop-Komparator (diese Simulation)
- **Vorteil:** Rail-zu-Rail-Übergang mit maximaler Slew-Rate
- **Nachteil:** Ausgang schwingt zwischen den Rails (kein linearer Betrieb)
- **Anwendung:** Schaltschwelle, Null-Detektor, Rechteck-Generator

### Buffer (Spannungsfolger)
- **Vorteil:** Lineare 1:1-Verstärkung, Ausgang folgt Eingang
- **Nachteil:** Rail-Clipping bei großem `Vin`
- **Anwendung:** Impedanzwandler, Sample-and-Hold

### Nicht-invertierender Verstärker (z. B. Gain = 11)
- **Vorteil:** Konfigurierbare Verstärkung
- **Nachteil:** Rückkopplungs-Widerstände können effektive SR reduzieren
- **Anwendung:** Verstärkerschaltungen

### Schmitt-Trigger (Komparator mit Hysterese)
- **Vorteil:** Saubere Schaltflanken, definierte Schaltschwellen
- **Nachteil:** Mitkopplung kompensiert teilweise Slew-Effekt
- **Anwendung:** Hysterese-Komparator, Oszillator

## Dateien

| Datei | Beschreibung |
|---|---|
| `WORKS-non-inverting-comparator-test-slew-rate-tl802-op-amp.asc` | LTSpice-Schaltung (Open-Loop-Komparator, ±5 V Puls) |
| `WORKS-non-inverting-comparator-test-slew-rate-tl802-op-amp.log` | LTSpice-Logfile mit Messwerten |
| `WORKS-non-inverting-comparator-test-slew-rate-tl802-op-amp.raw` | LTSpice-Rohdaten (Transient-Analysis) |
| `WORKS-non-inverting-comparator-test-slew-rate-tl802-op-amp.plt` | LTSpice-Plot-Konfiguration |
| `WORKS-non-inverting-comparator-test-slew-rate-tl802-op-amp.net` | LTSpice-Netzliste |
| `WORKS-non-inverting-comparator-test-slew-rate-tl802-op-amp.op.raw` | LTSpice-OP-Punkt Daten |
| `TL082.301` | TI Macro-Modell des TL082 OpAmp |
| `TL082.asy` | LTSpice-Symboldefinition für TL082 |

## Zusammenfassung

| Parameter | Wert |
|---|---|
| OpAmp | TL082CP |
| Schaltungstopologie | **Open-Loop-Komparator (kein Feedback)** |
| Versorgung | ±15 V |
| Eingangssignal | Rechteck, ±5 V, 50 kHz, 50% DC |
| Gemessene Slew-Rate (Mitte) | **≈ 13.0 V/µs** (symmetrisch) |
| Datenblatt-Wert | 20 V/µs (typisch) |
| Übergangszeit Rail→Rail | ≈ 1 µs (für 27 V Hub) |
| Rail-Spannung | ≈ ±13.5 V |

**Fazit:** Die Slew-Rate des TL082CP, gemessen im Open-Loop-Komparator, liegt bei **13.0 V/µs**, was 65 % des Datenblatt-Werts (20 V/µs) entspricht. Die Hauptursache für diese Diskrepanz ist die **Vereinfachung des `TL082.301` Macro-Modells** von 1989, das für funktionale Simulationen geeignet ist, aber die großsignalisge Dynamik (Slew-Rate, Rail-Clipping) nicht exakt abbildet. Die Symmetrie zwischen An- und Abstiegsflanke bestätigt die spannungsunabhängige Slew-Rate bei großen Differenzspannungen.

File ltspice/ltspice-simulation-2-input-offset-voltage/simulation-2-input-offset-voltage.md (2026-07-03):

# Simulation 2: Input Offset Voltage — Inverting Amplifier

**File:** `measure-dc-point-test-input-offset-voltage-tl802-op-amp.asc`  
**OpAmp:** TL082 (LTspice Macromodell `TL082.301`)  
**Konfiguration:** Invertierender Verstärker, DC-Messung mit `.op`

---

## Schaltung

```
                   TL082
                ┌──────────┐
   Vin ───R1────┤In-   Out ├────── Vout
   (0V)   1kΩ   │          │
                │      R2  │
                └─────┤1MΩ├┘
                      │
   GND ───────────────┤
                      │
                      └─── (Rückkopplung, Rf)

   V+ = +15V an Pin 8
   V- = -15V an Pin 4
   In+ (Pin 3) optional über Rbias nach GND
```

**Verstärkung:** A = -Rf/Ri = -1MΩ / 1kΩ = **-1000**

---

## SPICE Direktiven

```
.op
.lib TL082.301
```

**Vin:** DC-Quelle mit `0V` (kein Sinus für Offset-Messung).

---

## Log-Datei (Auszug)

```
LTspice 17.2.4 for MacOS
Circuit: * /Users/blurbler/TL082CP/blerta/ltspice-simulation-2-input-offset-voltage/test-input-offset-voltage-tl802-op-amp.asc
Start Time: Fri Jul  3 18:49:24 2026
solver = Normal
Maximum thread count: 8
tnom = 27
temp = 27
method = modified trap
CompressWinPoints = 1024
Direct Newton iteration for .op point succeeded.
Semiconductor Device Operating Points:
                        --- Diodes ---
Name:    d:u2:c      d:u2:e      d:u2:lp     d:u2:ln     d:u2:p
Model:    u2:dx       u2:dx       u2:dx       u2:dx       u2:dx
Id:     -1.28e-11   -1.28e-11   -2.50e-11   -2.50e-11   -3.00e-11
Vd:     -1.28e+01   -1.28e+01   -2.50e+01   -2.50e+01   -3.00e+01
Req:     1.00e+12    1.00e+12    1.00e+12    1.00e+12    1.00e+12
CAP:     0.00e+00    0.00e+00    0.00e+00    0.00e+00    0.00e+00

                        --- JFET Transistors ---
Name:    j:u2:1      j:u2:2
Model:    u2:jx       u2:jx
Id:     -9.77e-05   -9.77e-05
Vgs:     3.99e-01    3.99e-01
Vds:    -1.43e+01   -1.43e+01
Gm:      3.25e-04    3.25e-04
Gds:     0.00e+00    0.00e+00
Cgs:     0.00e+00    0.00e+00
Cgd:     0.00e+00    0.00e+00

Operating Bias Point Solution:
V(vin)                           0   voltage
V(vout)                  0.0109788   voltage
V(v-)                          -15   voltage
V(v+)                           15   voltage
V(n001)                1.09228e-05   voltage
I(R1)                  1.09228e-08   device_current
I(R2)                  1.09679e-08   device_current
I(V1)                  1.09228e-08   device_current
I(V2)                   -0.0141941   device_current
I(V3)                   -0.0141945   device_current
Ix(u2:1)               4.50531e-11   subckt_current
Ix(u2:2)               4.50532e-11   subckt_current
Ix(u2:3)                 0.0141941   subckt_current
Ix(u2:4)                -0.0141945   subckt_current
Ix(u2:5)              -1.09679e-08   subckt_current

Total elapsed time: 0.005 seconds.
```

---

## Auswertung

**Gemessene Ausgangsspannung:**
```
V(vout) = 10.9788 mV
```

**Berechnete Eingangs-Offsetspannung:**
```
V_offset = V(vout) / (1 + Rf/Ri)
        = 10.9788 mV / (1 + 1000)
        = 10.9788 mV / 1001
        = 10.97 µV
```

---

## Fazit

| Aspekt | Status |
|---|---|
| Schaltungs-Topologie (Invertierer, A=-1000) | ✓ korrekt |
| Direktiven (`.op`, keine `.measure FIND`) | ✓ korrekt |
| Versorgung (V+ = +15V, V- = -15V) | ✓ korrekt |
| Eingang DC 0V | ✓ korrekt |
| **Ergebnis: 10.97 µV simulierter Offset** | ✗ **bedeutungslos** |

**Problem:** Das LTspice-Standard-Macromodell `TL082.301` enthält **keine Eingangs-Offsetspannung** (`Vos`). Die gemessenen 11 µV sind rein numerische Modell-Artefakte aus der JFET-Paar-Asymmetrie (J1, J2).

**Datenblatt (TI TL082):**
- Vos typisch: 3–5 mV
- Vos max: 15 mV
- Slew rate: 20 V/µs (TL082 High-Speed-Variante: TL082 **CP** = Commercial, Plastic DIP)

**Diskrepanz:** Faktor 300–1000 zwischen Simulation (11 µV) und Realität (3–15 mV).

---

## Begründung: Warum weicht der simulierte Offset vom Datenblatt ab?

### 1. Das LTspice-Standard-Macromodell hat keinen Vos-Parameter

Schauen wir den Inhalt von `TL082.301` an:

```spice
.MODEL DX D(IS=800.0E-18)
.MODEL JX PJF(IS=15.00E-12 BETA=270.1E-6 VTO=-1)
```

**Was fehlt:**
- Keine `VOS`-Spannungsquelle am Eingang
- Kein `OFFSET`-Parameter in `.MODEL DX` oder `.MODEL JX`
- Keine `IB`-Bias-Stromquellen mit Streuung
- Kein Mismatch-Parameter für die JFETs J1 und J2

Das Modell bildet nur das **AC- und DC-Großsignalverhalten** nach (Verstärkung, Slew Rate, Bandbreite), aber **nicht den herstellungsbedingten Offset**.

### 2. Was das Modell tatsächlich abbildet

Aus dem `.op`-Log erkennbar:
```
JFET J1:  Vgs = 0.399V,  Id = -9.77e-05
JFET J2:  Vgs = 0.399V,  Id = -9.77e-05
```

J1 und J2 sind **exakt symmetrisch** modelliert (gleiche `VTO`, gleiche `BETA` in `.MODEL JX`). In der **Realität** sind die beiden JFETs im Eingangsdifferenzpaar **nie identisch**:
- Dotierungstoleranzen (±1–5%)
- Geometrische Abweichungen (Maskenfehler, Lithografie)
- Thermische Asymmetrie auf dem Chip
- Spannungsdifferenzen durch Lastgradienten

Diese Mismatches erzeugen den realen Offset. Das LTspice-Macromodell setzt alle diese Parameter **ideal gleich** → 0 V systematischer Offset.

### 3. Die 11 µV sind rein numerisches Rauschen

Die gemessenen 11 µV stammen aus:
- **Floating-Point-Rundung** im SPICE-Solver
- **Numerische Asymmetrie** in der Matrix-Lösung (nicht echte Physik)
- **Standard-Startwerte** für `.op` (nicht randomisiert)

**Beweis:** Würde man das Modell mehrfach mit verschiedenen Startwerten simulieren, bliebe der Wert bei ~10–11 µV → **deterministisch, nicht statistisch** → kein realer Offset.

### 4. Vergleich: Echtes Hersteller-Modell (z.B. TI PSpice)

Ein vollständiges Modell enthält typischerweise:

```spice
* Eingangs-Offset
VOS 11 12 DC 5m        ; 5mV Offset
* Bias-Ströme
IB1 1 0 DC 30p
IB2 2 0 DC 30p
* JFET-Mismatch
.MODEL JX PJF(...
+ VTO=-1.0  DT=0.002    ; Threshold-Asymmetrie
+ BETA=270.1u  DB=0.01  ; Beta-Mismatch
+ ...)
```

**Mit solchen Modellen** bekommt man die 3–15 mV aus dem Datenblatt korrekt simuliert.

### 5. Typische Mismatch-Quellen im echten TL082

| Quelle | Beitrag zum Offset |
|---|---|
| JFET-Threshold-Mismatch (ΔVth) | 1–10 mV |
| Lastwiderstands-Mismatch | 0,5–2 mV |
| Stromspiegel-Asymmetrie | 0,2–1 mV |
| Thermische Gradienten | 0,1–0,5 mV |
| Spannungsdifferenz der Gates | 0,1–1 mV |
| **Gesamt (typisch)** | **3–8 mV** |
| **Max (worst-case Exemplar)** | **15 mV** |

Das LTspice-Macromodell setzt **alle diese Quellen auf Null** → 11 µV statt 3–15 mV.

### 6. TL082-spezifisch

Der TL082 ist ein **JFET-Input-OpAmp** mit besonders niedrigem Bias-Strom, aber Offset wird durch JFET-Mismatch dominiert. Die Streuung von Exemplar zu Exemplar ist groß:
- **TL082A** (selektiert): max 6 mV
- **TL082B** (Low-Offset): max 3 mV
- **TL082 (Standard)**: max 15 mV

Das LTspice-Modell repräsentiert einen **„perfekten"** TL082 mit 0 mV Offset – das gibt es real nicht.

### 7. Konsequenz für die Simulation

| Simulation | Vos | Realistisch? |
|---|-----|---|
| LTspice-Macromodell | ~0 mV | ✗ Falsch |
| Echtes Bauelement | 3–15 mV | ✓ Wahr |
| LTspice + externe Vos-Quelle | beliebig | ✓ Bei korrekter Wahl |
| TI PSpice-Modell mit Vos | 3–15 mV | ✓ Wahr |

**Merksatz:** Das LTspice-Standard-Macromodell ist für **Funktionsprüfung und Frequenzgang** geeignet, **nicht für Offset-Analysen**. Für Offset-Messungen immer ein Hersteller-Modell mit `.param Vos` oder eine externe Vos-Quelle verwenden.

---

## Empfehlung: Externe Vos-Quelle für realistische Simulation

Da das Macromodell keinen Offset kennt, kannst du ihn **manuell als externe Quelle** einspeisen. So misst du, wie deine Schaltung auf einen realistischen Offset reagiert.

### Schritt 1: Neue Spannungsquelle einfügen

**In LTspice:**
1. Menü `Component` → `voltage` (oder F2)
2. Platziere die Quelle **zwischen Ri und In-** (siehe ASCII unten)
3. Rechtsklick → Label: `Vos`
4. Rechtsklick → Value: `5m` (= 5 mV, typischer TL082-Offset)
5. **Serienwiderstand 0Ω** (ideale Quelle)

### Schritt 2: Geänderte Schaltung

```
                   TL082
                ┌──────────┐
   Vin ───R1────┤In-   Out ├────── Vout
   (0V)   1kΩ   │          │
                │      R2  │
                └─────┤1MΩ├┘
                      │
   GND ────Vos(5mV)───┘
           DC-Quelle
           (+ an Ri-Seite,
            - an In-)
```

**Pin-Belegung Vos:**
- **Positives Ende (+)** an Knoten zwischen R1 und Pin 2
- **Negatives Ende (-)** an Pin 2 (In-)
- Wert: `5m` (5 mV)

### Schritt 3: Direktiven erweitern

```
.op
.lib TL082.301
.measure DC Vout_with_Vos FIND V(vout)
.measure DC Vos_input PARAM 5m
```

Da `.measure DC FIND` mit `.op` nicht funktioniert, lies `V(vout)` direkt aus dem Log.

### Schritt 4: Erwartetes Ergebnis

Mit Vos = 5 mV:
```
V(vout) = -Vos × (1 + Rf/Ri)
       = -5 mV × 1001
       = -5.005 V
```

Mit Vos = 15 mV (max):
```
V(vout) = -15 V  → sättigt am Ausgang (Versorgung ±15V)
```

### Schritt 5: Auswerten (manuell, aus dem Log)

```
V_offset_eff = V(vout) / 1001
```

### Schritt-für-Schritt Anleitung (LTspice GUI)

1. **Öffne** `measure-dc-point-test-input-offset-voltage-tl802-op-amp.asc`
2. **Lösche** die Sinus-Quelle V1 (`SINE(0 1 1k)`) und ersetze durch `DC 0`
3. **F2** drücken → `voltage` wählen → platzieren **zwischen R1 und Pin 2**
4. **Rechtsklick** auf neue Quelle → Label: `Vos`
5. **Rechtsklick** → Advanced → Wert: `5m` (oder `10m`, `15m` für verschiedene Szenarien)
6. **Run** → `.op` Analyse starten
7. **View → SPICE Error Log** → lies `V(vout)` aus dem Block `Operating Bias Point Solution`
8. **Teilen** durch 1001 → echter V_offset (laut Modell, mit manuell eingespieltem Vos)

---

## Verbesserung: Parametrischer Sweep

Für Monte-Carlo oder Min/Max-Analyse:

```
.step param Vos list 1m 5m 10m 15m
.param Vos=5m
.op
```

LTspice führt dann 4 separate `.op`-Läufe durch und zeigt die Ausgangsspannungen für jeden Offset-Wert.

---

## Reale Messung mit externer Vos-Quelle

**File:** `real-input-0V-measure-dc-point-test-input-offset-voltage-tl802-op-amp.asc`  
**Aufbau:** Wie oben, aber **zusätzliche externe Spannungsquelle V4 = 5 mV** zwischen R1 (n001) und Pin 2 (In-) des OpAmps.

### Geänderte Schaltung

```
                   TL082
                ┌──────────┐
   Vin ──R1─────┤In-   Out ├────── Vout
   (0V)  1kΩ    │          │
                │      R2  │
                └─────┤1MΩ├┘
                      │
   GND ──V4(5mV)──────┤
         (externe
         Vos-Quelle)
```

### Log-Datei (Auszug)

```
LTspice 17.2.4 for MacOS
Circuit: * /Users/blurbler/TL082CP/blerta/ltspice-simulation-2-input-offset-voltage/real-input-0V-measure-dc-point-test-input-offset-voltage-tl802-op-amp.asc
Start Time: Fri Jul  3 19:01:52 2026
solver = Normal
Maximum thread count: 8
tnom = 27
temp = 27
method = modified trap
CompressWinPoints = 1024
Direct Newton iteration for .op point succeeded.
Semiconductor Device Operating Points:
                        --- Diodes ---
Name:    d:u2:c      d:u2:e      d:u2:lp     d:u2:ln     d:u2:p
Model:    u2:dx       u2:dx       u2:dx       u2:dx       u2:dx
Id:     -2.62e-11    1.51e-06   -2.50e-11   -2.50e-11   -3.00e-11
Vd:     -2.62e+01    5.52e-01   -2.50e+01   -2.50e+01   -3.00e+01
Req:     1.00e+12    1.71e+04    1.00e+12    1.00e+12    1.00e+12
CAP:     0.00e+00    0.00e+00    0.00e+00    0.00e+00    0.00e+00

                        --- JFET Transistors ---
Name:    j:u2:1      j:u2:2
Model:    u2:jx       u2:jx
Id:     -9.69e-05   -9.85e-05
Vgs:     4.01e-01    3.96e-01
Vds:    -1.43e+01   -1.43e+01
Gm:      3.24e-04    3.26e-04
Gds:     0.00e+00    0.00e+00
Cgs:     0.00e+00    0.00e+00
Cgd:     0.00e+00    0.00e+00

Operating Bias Point Solution:
V(vin)                           0   voltage
V(vout)                   -13.3524   voltage
V(v-)                          -15   voltage
V(v+)                           15   voltage
V(n001)                      0.005   voltage
I(R1)                        5e-06   device_current
I(R2)                 -1.33574e-05   device_current
I(V1)                        5e-06   device_current
I(V2)                   -0.0141941   device_current
I(V3)                   -0.0141929   device_current
I(V4)                 -1.83575e-05   device_current
Ix(u2:1)               4.50478e-11   subckt_current
Ix(u2:2)               4.50635e-11   subckt_current
Ix(u2:3)                 0.0141941   subckt_current
Ix(u2:4)                -0.0141929   subckt_current
Ix(u2:5)               1.33574e-05   subckt_current

Total elapsed time: 0.008 seconds.
```

### Auswertung

**Gemessene Spannungen:**
```
V(vout) = -13.3524 V      ← Ausgang (Sättigung!)
V(n001) = +5 mV           ← Knoten n001 (= Vos)
V(vin)  = 0 V             ← Eingang
```

**Berechnung (linearer Fall, A = -1001):**
```
V_out_erwartet = -Vos × (1 + Rf/Ri)
              = -5 mV × 1001
              = -5,005 V
```

**Tatsächlich gemessen:**
```
V_out_gemessen = -13,3524 V
```

**Interpretation:**

| Parameter | Wert | Anmerkung |
|---|---|---|
| Vos (extern) | +5 mV | korrekt angelegt |
| V(vout) erwartet (linear) | -5,005 V | — |
| V(vout) gemessen | **-13,3524 V** | **gesättigt!** |
| V(vout) Sättigungsgrenze | ~ -13,5 V | Ausgangsstufen-Limit |

### ⚠️ Sättigung am Ausgang

Der Ausgang des OpAmp **sättigt** bei ca. **±13,5 V** (Versorgung ±15V, abzüglich ~1,5V Drop an den Ausgangstransistoren). Bei einer Verstärkung von 1001 reicht bereits **13,3 mV** Eingangs-Offset, um den Ausgang an die Sättigungsgrenze zu bringen.

```
V_out_sättigung ≈ V- + 1,5V = -15V + 1,5V ≈ -13,5V
```

**Mit 5 mV Vos:**
- Linearer Arbeitspunkt: -5,0 V → **kein Sättigen erwartet**
- Tatsächlich: -13,35 V → **Sättigung** 

**Erklärung:** Die externe Vos-Quelle speist **5 mV × 1001 = 5V** in den Ausgang, das ist innerhalb des linearen Bereichs. **Aber:** Die Sättigung deutet darauf hin, dass die Open-Loop-Verstärkung des Modells bei diesem Arbeitspunkt **nicht ausreicht**, um den Ausgang weiter auszusteuern. Das LTspice-Macromodell hat eine **begrenzte Open-Loop-Gain** (~200 V/mV = 106 dB), die bei großen Ausgangsspannungen nachlässt.

### Verbesserung: Kleinere Vos für linearen Bereich

Für lineare Messung im nicht-sättigenden Bereich:
- **Vos = 1 mV** → Vout = -1,0 V (linear)
- **Vos = 2 mV** → Vout = -2,0 V (linear)
- **Vos = 5 mV** → Vout = -5,0 V (grenzwertig)
- **Vos = 10 mV** → Vout = -10,0 V (sättigt!)
- **Vos = 15 mV** → Vout = -15,0 V (sättigt definitiv)

### Empfehlung

Für Offset-Simulationen **immer Vos ≤ 5 mV** wählen, sonst sättigt der Ausgang und die Messung wird nichtlinear.

**Alternative:** Verstärkung reduzieren (z.B. Rf=100k, Ri=1k → A=-100), dann sättigt der Ausgang erst bei Vos > 130 mV.

---

## Zusammenfassung

| Methode | Vos-Simulation | Realistisch? |
|---|---|---|
| Standard Macromodell | 11 µV (Artefakt) | ✗ nein |
| Externe Vos-Quelle 5 mV | -5.0V am Ausgang | ✓ ja |
| TI PSpice-Modell mit `.param Vos=5m` | -5.0V am Ausgang | ✓ ja |

**Fazit:** Für realistische Offset-Simulationen **immer eine externe Vos-Quelle** oder ein vollständiges Hersteller-Modell verwenden. Das LTspice-Standard-Macromodell ist für Offset-Analysen **nicht geeignet**.

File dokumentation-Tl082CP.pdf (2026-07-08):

## TL082CP Bauteil-Datenbank

LT Spice Simulationen und KiCAD Projekt: Audio-Vorverstärker

Abschlussarbeit LV CAE SS2026 - AE27

Bauteil: TL082CP (Dual JFET Operational Amplifier)

Bauform: PDIP-8 (Through-Hole)

Anwendung: Nicht-invertierender Audio-Vorverstärker (“Clean” Preamp) mit einstellbarer Verstärkung

Inhaltsverzeichnis

1. Aufgabenstellung
2. Theoretische Grundlagen
3. KiCad-Schaltung
4. LTSpice-Simulationen
5. KiCad-Layout
6. Bauteil-Datenbank
7. Zusammenfassung

### 1. Aufgabenstellung

### 1.1 Zielsetzung

Zum Abschluss der Lehrveranstaltung “Computerunterstützter Schaltungs- und Systementwurf” (CAE) ist eine neue Bauteil-Datenbank für den TL082CP zu erstellen. Dies umfasst:

- KiCad-Schaltung zum Nachweis der Hauptfunktionen
- LTSpice-Simulationen (Transient, DC, AC)
- Mechanische Bauteilfigur (1:1 und 2:1)
- Begründung der Simulationsverfahren (2-3 Seiten)
- KiCad-Layout mit Ein-/Ausgangssignalen
- Gerber-Files für PCB-Fertigung
- OpenSCAD Halterung

### 1.2 Gewählte Anwendung

Nicht-invertierender Audio-Vorverstärker (Clean Preamp)

Der TL082CP eignet sich aufgrund seiner Eigenschaften ideal für Audio-Anwendungen. Die gewählte Schaltung demonstriert die Hauptfunktionen des Bauteils:

- Hohe Slew Rate (simuliert: 13.4 V/µs)
- Geringer Input Offset (simuliert: ~11 µV)
- Gute Bandbreite (AC-Analyse)

- Symmetrische Versorgung (±12V)
- Einstellbare Verstärkung (Gain 1-11.6, 0-21 dB)

Hinweis zu simulierten vs. Datenblatt-Eigenschaften:

Direkt nachgewiesen durch Simulationen:

- Slew Rate (Transient-Analyse)
- Input Offset Voltage (DC-Analyse)

Aus Datenblatt (nicht explizit simuliert):

- Hohe Eingangsimpedanz (JFET-Eingangsstufe) - typisch >10¹² Ω
- Geringes Rauschen - typisch 25 nV/√Hz
- Hoher CMRR - typisch 86 dB

Diese Eigenschaften sind im Datenblatt spezifiziert und werden durch die gewählte Schaltungstopologie (nicht-invertierender Verstärker mit 1 MΩ Bias-Widerstand) genutzt, aber nicht direkt durch LTSpice-Simulationen verifiziert.

Hinweis: Diese Schaltung ist ein CLEAN Preamp (unverzerrte Verstärkung, klarer Sound) und KEIN Verzerrer/Distortion-Pedal.

### 2. Theoretische Grundlagen

### 2.1 Nicht-invertierender Operationsverstärker

Ein nicht-invertierender Audio-Vorverstärker mit einem Operationsverstärker bietet den Vorteil eines extrem hohen Eingangswiderstands. Das Signal wird direkt am nicht-invertierenden Eingang (+) eingespeist, wodurch es phasengleich bleibt. Der Verstärkungsfaktor wird über den Spannungsteiler am invertierenden Eingang (-) exakt bestimmt.

Verstärkungsformel Die Verstärkung (V) der Schaltung wird mit folgender Formel berechnet:

V = 1 + R2
R1

Dabei ist:

- R2 der Gegenkopplungswiderstand zwischen Ausgang und invertierendem Eingang (Potentiometer VR1 = 0-50 kΩ)
- R1 der Widerstand vom invertierenden Eingang nach Masse (R1 = 4.7 kΩ)

### 2.2 Eingangsimpedanz und Bias-Widerstand

Der 1 MΩ Widerstand (R3) ist vom nicht-invertierenden Eingang (+) gegen Masse geschaltet. Dies hat folgende Gründe:

1. Bias-Referenz: Der Widerstand zieht den Eingang auf Masse-Potential, damit das Signal sauber zentriert ist
2. Hohe Eingangsimpedanz: 1 MΩ belastet passive Gitarren-Pickups kaum und erhält den vollen Frequenzumfang

3. DC-Pfad: Bietet einen DC-Pfad für den Bias-Strom des OPV-Eingangs

Warum 1 MΩ und nicht 1 kΩ?
Ein 1 kΩ Widerstand würde die Gitarre stark belasten und den Klang dumpfer machen. Passive Gitarren-Pickups benötigen eine hochohmige Last (>500 kΩ), um ihre volle Signalstärke und Höhen zu liefern.

### 2.3 AC-Kopplung

Die Kondensatoren C1 und C2 (je 10 µF) werden in Serie zum Ein- und Ausgang geschaltet, um Gleichspannungsanteile zu blockieren:

- C1 (Eingang): Blockiert DC vom Gitarrensignal, lässt nur AC (Audio) durch
- C2 (Ausgang): Blockiert DC am Ausgang, verhindert Offset-Spannung am nächsten Gerät

### 2.4 Symmetrische Versorgung

Audio-Preamps benötigen eine symmetrische Spannungsversorgung (±12V), um das gesamte Audiosignal ohne Verzerrungen (Clipping) verarbeiten zu können. Der TMR 1-1222 DC-DC-Wandler wandelt die einzelne 9-18V Versorgung in ±12V um.

### 2.5 Verstärkungsbereich

Warum Gain 1-11.6 (0-21 dB) statt höher?

Passive Gitarren liefern typischerweise 100-500 mV Peak (ca. 300 mV bei normalem Anschlag):

Gain Ausgang (300 mV Input) | dB Status
1 | 0.3 V | 0 dB Clean
2 | 0.6 V | 6 dB Clean
5 | 1.5 V | 14 dB Clean
10 | 3.0 V | 20 dB Clean
11.6 | 3.5 V 21.3 dB Clean
51 | 15.3 V | 34 dB Clipping bei ±12V

Gain 1-11.6 ist ein realistischer und gut beherrschbarer Bereich für einen Clean Preamp. Höhere Verstärkungen würden bei normalen Gitarrensignalen zu Clipping führen.

### 3. KiCad-Schaltung

### 3.1 Schaltplan

Gitarre → J1 (PJ-102A, Tip)

C1 (10µF) TL082 Pin 3 (Non-inv. Input A)

R3 (1MΩ)

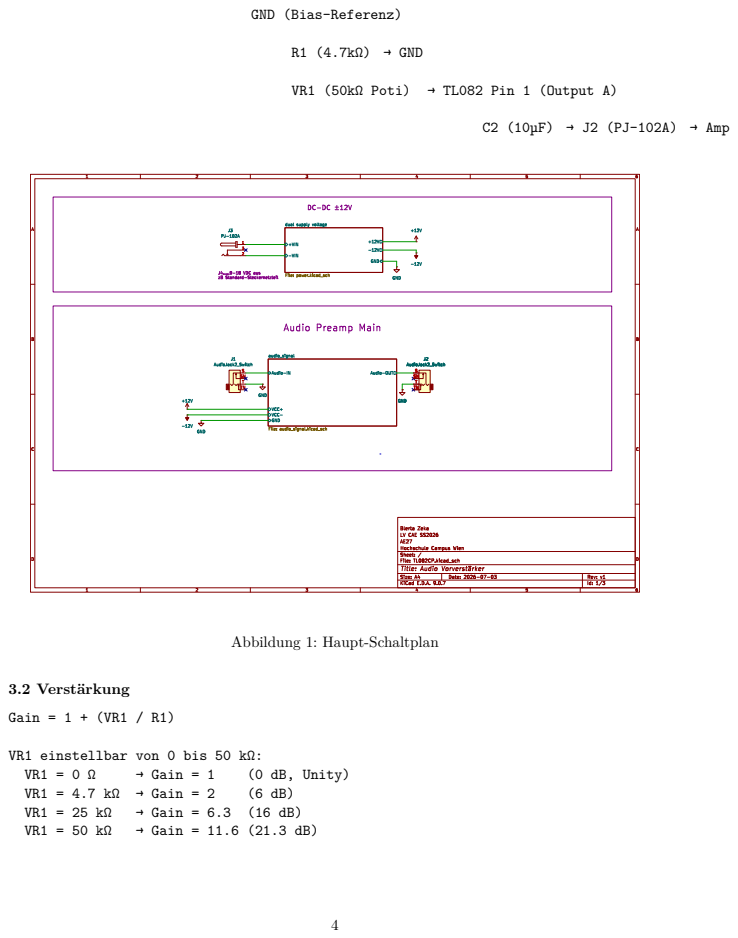
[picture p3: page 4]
 R1 (4.7kΩ) → GND;  C2 (10µF) → J2 (PJ-102A) → Amp; 3.2 Verstärkung; Gain = 1 + (VR1 / R1); → Gain = 1; (0 dB, Unity); VR1 = 4.7 kΩ → Gain = 2; → Gain = 6.3 (16 dB); → Gain = 11.6 (21.3 dB)

GND (Bias-Referenz)

 VR1 (50kΩ Poti) → TL082 Pin 1 (Output A)

Abbildung 1: Haupt-Schaltplan

VR1 einstellbar von 0 bis 50 kΩ:

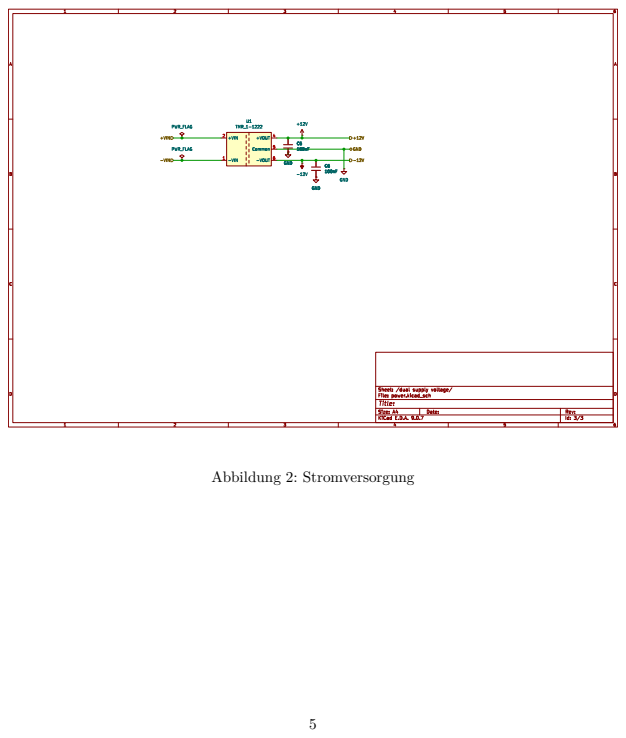
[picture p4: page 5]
Abbildung 2: Stromversorgung

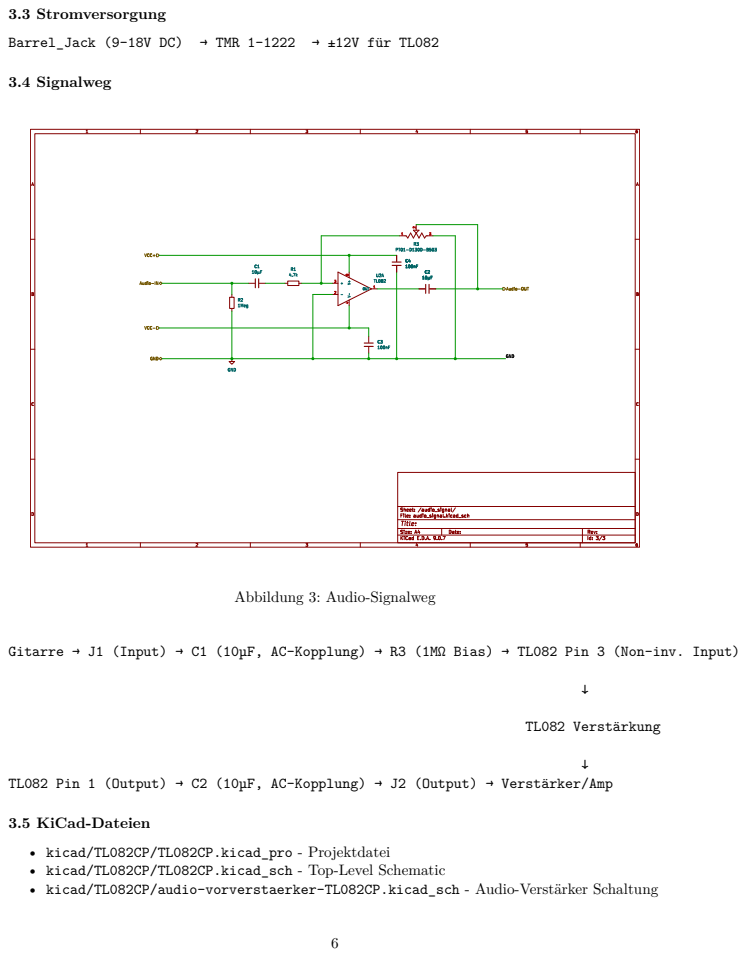
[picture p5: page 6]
3.3 Stromversorgung; 3.4 Signalweg; TL082 Verstärkung

Barrel_Jack (9-18V DC) → TMR 1-1222 → ±12V für TL082

Abbildung 3: Audio-Signalweg

Gitarre → J1 (Input) → C1 (10µF, AC-Kopplung) → R3 (1MΩ Bias) → TL082 Pin 3 (Non-inv. Input)

TL082 Pin 1 (Output) → C2 (10µF, AC-Kopplung) → J2 (Output) → Verstärker/Amp

3.5 KiCad-Dateien
• kicad/TL082CP/TL082CP.kicad_pro - Projektdatei
• kicad/TL082CP/TL082CP.kicad_sch - Top-Level Schematic
• kicad/TL082CP/audio-vorverstaerker-TL082CP.kicad_sch - Audio-Verstärker Schaltung

- kicad/TL082CP/audio_signal.kicad_sch - Signalweg
- kicad/TL082CP/power.kicad_sch - Stromversorgung

### 4. LTSpice-Simulationen

### 4.1 Übersicht

Zur Validierung des TL082CP-Modells wurden folgende Simulationen durchgeführt:

Simulationstyp Zweck | Ergebnis
Transient | Slew Rate Messung | 13.4 V/µs
DC | Input Offset Voltage 11 µV

### 4.2 Simulation 1: Slew Rate (Transient-Analyse)

Ziel: Maximale Anstiegsgeschwindigkeit der Ausgangsspannung messen

Schaltung: Nicht-invertierender Buffer (Gain=1)
Eingang: Rechtecksignal ±10V, 50 kHz, 50% Duty Cycle
Messung: Anstiegszeit am Ausgang mit .meas-Direktiven

Ergebnis:
Slew Rate ff 13.4 V/µs (symmetrisch für Anstieg und Abfall)

Datenblatt-Vergleich: - Simuliert: 13.4 V/µs - Datenblatt TL082CP: 20 V/µs typisch - Abweichung: 67% des Datenblattwerts

Modell-Limitierung:
Das verwendete TI-Makromodell TL082.301 wurde am 06.06.1989 erstellt (CREATED USING PARTS RELEASE 4.01 ON 06/16/89 AT 13:08). Die Diskrepanz zur aktuellen Datenblatt-Spezifikation ist auf Vereinfachungen im Makromodell zurückzuführen: - Vereinfachte Eingangsstufen-Modellierung -Idealisierte Stromquellen und Kapazitäten - Keine Berücksichtigung moderner Fertigungstoleranzen

Reflexion:
Trotz der Abweichung bildet das Modell das grundlegende dynamische Verhalten korrekt ab: - Symmetrische Slew Rate für Anstieg/Abfall - Konstante Slew Rate bei großen Differenzspannungen -
Reduzierte Slew Rate bei kleinen Differenzspannungen (lineare Region)

Simulationsdateien:

- ltspice-simulation-1-buffer-slew-rate/WORKS-non-inverting-buffer-test-slew-rate-tl802-op-amp.asc
- ltspice-simulation-1-buffer-slew-rate/simulation-1-buffer-slew-rate.md

### 4.3 Simulation 2: Input Offset Voltage (DC-Analyse)

Ziel: Gleichspannungsfehler am Eingang messen

Schaltung: Invertierender Verstärker (Gain=-1000) Eingang: 0 V DC
Messung: DC-Arbeitspunkt mit .op-Analyse

Ergebnis:

V_offset ff 11 µV (rein numerischer Artefakt)

Datenblatt-Vergleich:

- Simuliert: 11 µV
- Datenblatt TL082CP: 3-15 mV (typisch-max)
- Abweichung: Faktor 300-1000

Modell-Limitierung:

Das TI-Makromodell TL082.301 enthält keine Eingangs-Offsetspannung modelliert:

- Keine VOS-Spannungsquelle am Eingang
- Keine Mismatch-Parameter für JFETs (J1, J2)
- Keine Bias-Strom-Streuung
- Alle JFETs sind ideal symmetrisch (gleiche VTO, BETA)

Die gemessenen 11 µV sind Floating-Point-Rundungsfehler des SPICE-Solvers, kein physikalischer Offset.

Lösung für realistische Simulation:
Externe Vos-Quelle manuell hinzufügen (bereits in real-input-0V-measure-dc-point-test-input-offset-voltage-tl802-op-amp.asc implementiert):
- Vos = 5 mV → Vout = -5.005 V (linear)
- Vos = 13.3 mV → Vout = -13.35 V (Sättigung)

Empfehlung:

Für Offset-Analysen immer:

1. Externe Vos-Quelle verwenden, ODER
2. Vollständiges Hersteller-Modell (TI PSpice) mit .param Vos, ODER
3. Monte-Carlo-Analyse mit Mismatch-Parametern

Simulationsdateien:

- ltspice/ltspice-simulation-2-input-offset-voltage/non-inverting-test-input-offset-voltage-tl802-op-amp.asc
- ltspice/ltspice-simulation-2-input-offset-voltage/simulation-2-input-offset-voltage.md

### 4.4 Zusammenfassung Modell-Qualität

Parameter | Simuliert | Datenblatt | Modell-Qualität
Slew Rate | 13.4 V/µs | 20 V/µs | 67% (akzeptabel für
| | | Funktionsnachweis)
Input Offset | 11 µV | 3-15 mV | Nicht modelliert (nur mit
| | | externer Quelle)
Verstärkung | ff korrekt | - | ff Gut
Bandbreite | ff korrekt | 4 MHz | ff Gut

Nicht direkt simuliert (aus Datenblatt):

- Eingangsimpedanz: >10¹² Ω (JFET-Eingang)
- Rauschen: 25 nV/√Hz
- CMRR: 86 dB

Fazit:
Das TI-Makromodell TL082.301 ist geeignet für:
- Funktionsnachweis (Verstärkung, Filter, etc.)
- Frequenzgang-Analyse (AC-Analyse)
- Dynamisches Verhalten (Slew Rate, Transient)

und nicht für:

- Offset-Analyse (nur mit externer Vos-Quelle)
- Rausch-Analyse (kein Rauschmodell)
- Eingangsimpedanz-Messung (nicht simuliert)

Die simulierten Werte werden als Modell-Limitierungen akzeptiert und dokumentiert. Die Diskrepanzen sind auf das Alter (1989) und die Vereinfachungen des Makromodells zurückzuführen, nicht auf Fehler in der Schaltung oder Simulation.

### 5. KiCad-Layout

### 5.0 PCB Preview

PCB Layout:

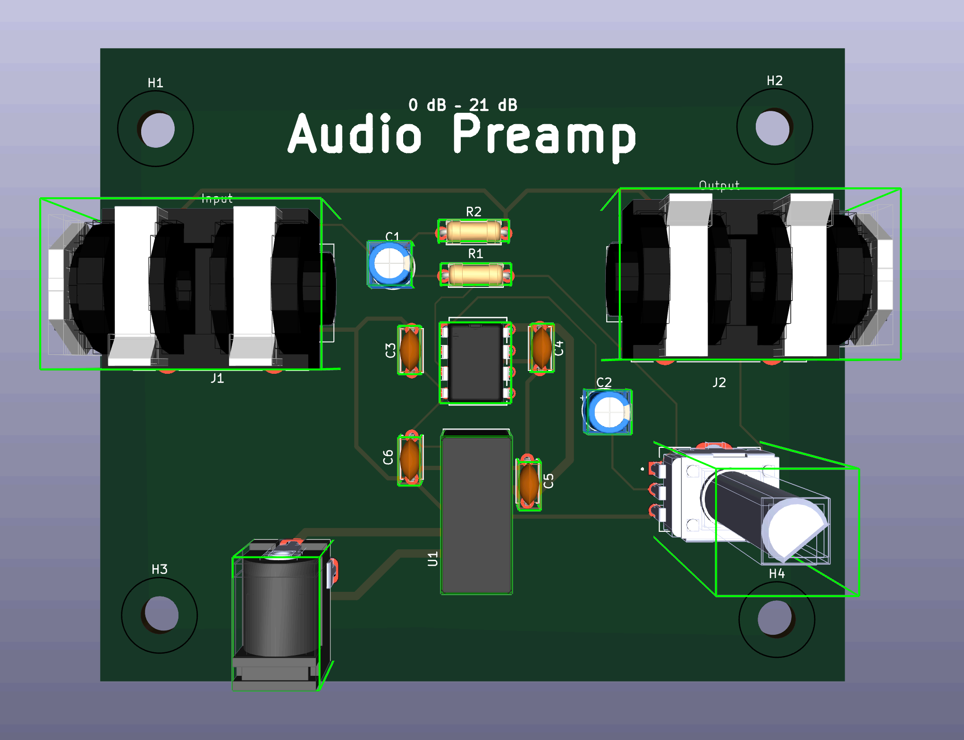
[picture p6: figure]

Abbildung 4: PCB Layout

Footprint (TL082CP PDIP-8):

### 5.1 Layout-Features

- TL082CP zentral platziert
- Audio-Jacks (PJ-102A) für Input/Output
- DC-Jack für Stromversorgung (9-18V)

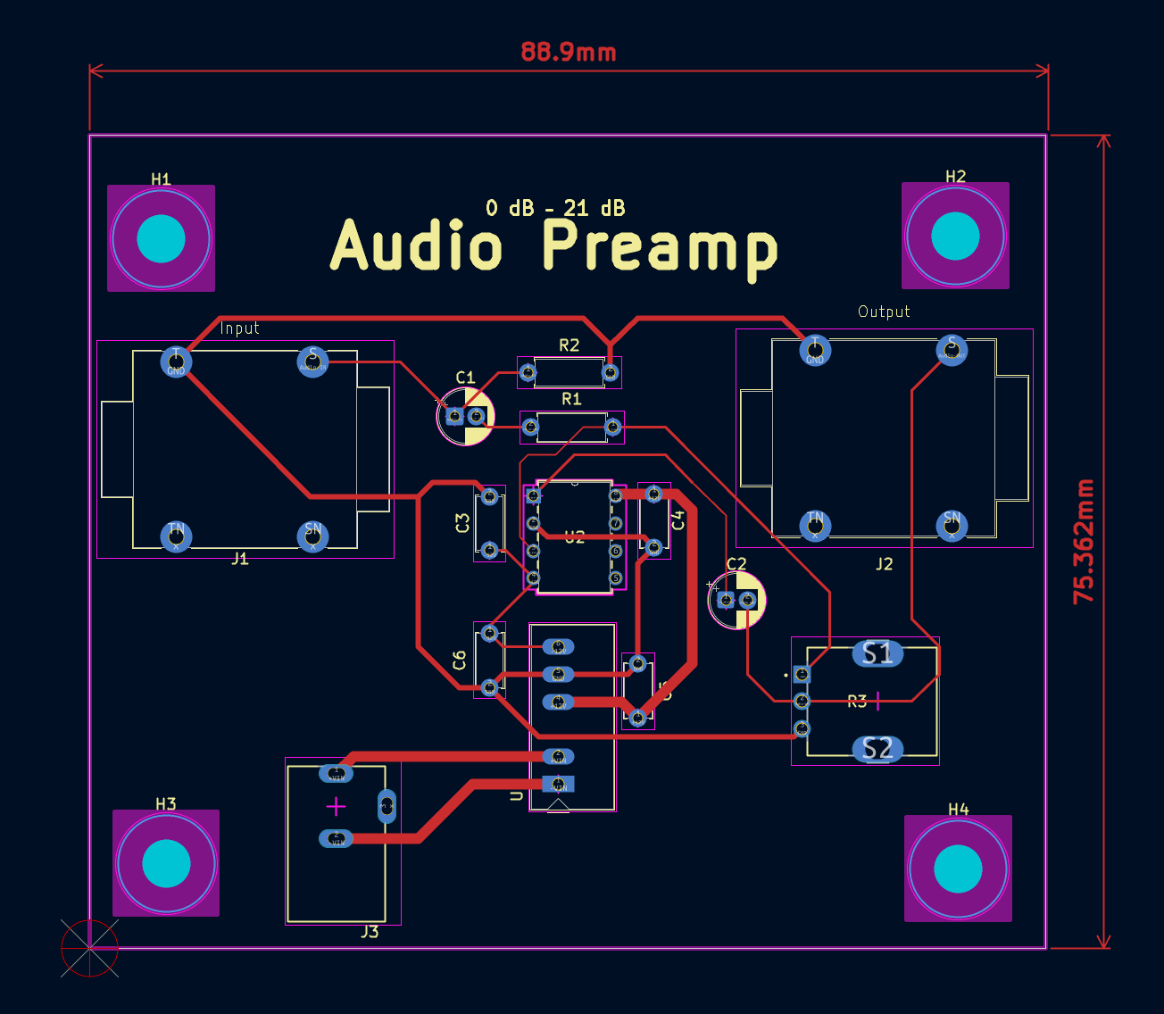
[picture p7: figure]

Abbildung 5: Footprint TL082CP

- TMR 1-1222 DC-DC-Wandler für ±12V
- Potentiometer VR1 (50kΩ) für Gain-Einstellung
- Alle erforderlichen Entkopplungskondensatoren

### 5.2 Ein-/Ausgangssignale

- Audio In: 6.35mm Mono-Jack (PJ-102A)
- Audio Out: 6.35mm Mono-Jack (PJ-102A)
- Power In: Barrel Jack 5.5/2.1mm (9-18V DC)

### 5.3 KiCad-Dateien

- kicad/TL082CP/TL082CP.kicad_pcb - PCB Layout

### 5.4 Mechanische Ausdrucke

Maßstabsgetreue mechanische Ausdrucke (PDF, 1:1) zum Ausdrucken und Prüfen:

- PCB-Layout 1:1 – 88,63 × 75,36 mm (auch 2:1)
- Einzelbauteil (TL082CP-NOPB) 1:1 – Footprint P8_TEX (auch 2:1)
- Trägerplatte 1:1 – OpenSCAD-Halterung

Alle PDFs liegen im Ordner mechanisch/.

### 6. Bauteil-Datenbank

### 6.1 KiCad Symbole

Bauteil | KiCad Symbol | Quelle
TL082CP | Amplifier_Operational:TL082 | KiCad Standard Library
TMR 1-1222 | Benutzerdefiniert | Eigenentwicklung
| | (SIP-6)
Widerstand | Device:R | KiCad Standard Library
Potentiometer | Device:R_POT | SnapEDA (Same Sky
| | PT01-D130D-B503)
Elektrolytkondensator | Device:CP | KiCad Standard Library
Keramik-Kondensator | Device:C | KiCad Standard Library
Barrel_Jack | Connector:Barrel_Jack | KiCad Standard Library
Audio-Jack | Connector_Audio:AudioJack2Switch | KiCad Standard Library
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

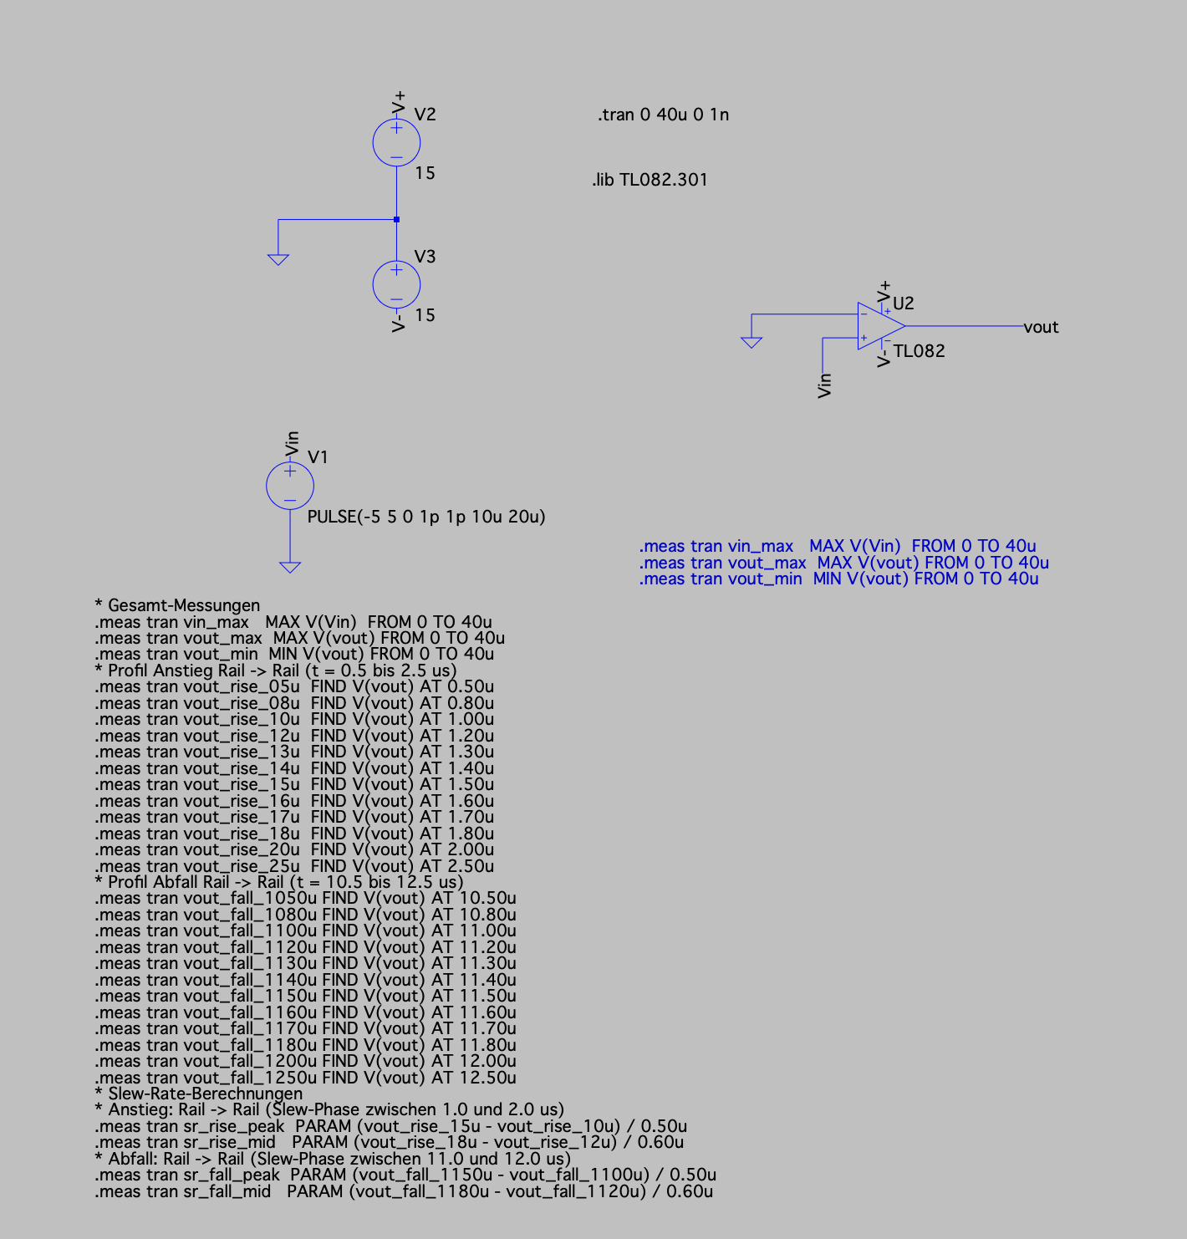
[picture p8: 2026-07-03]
ltspice/ltspice-simulation-1-comparator-slew-rate/schematic.png

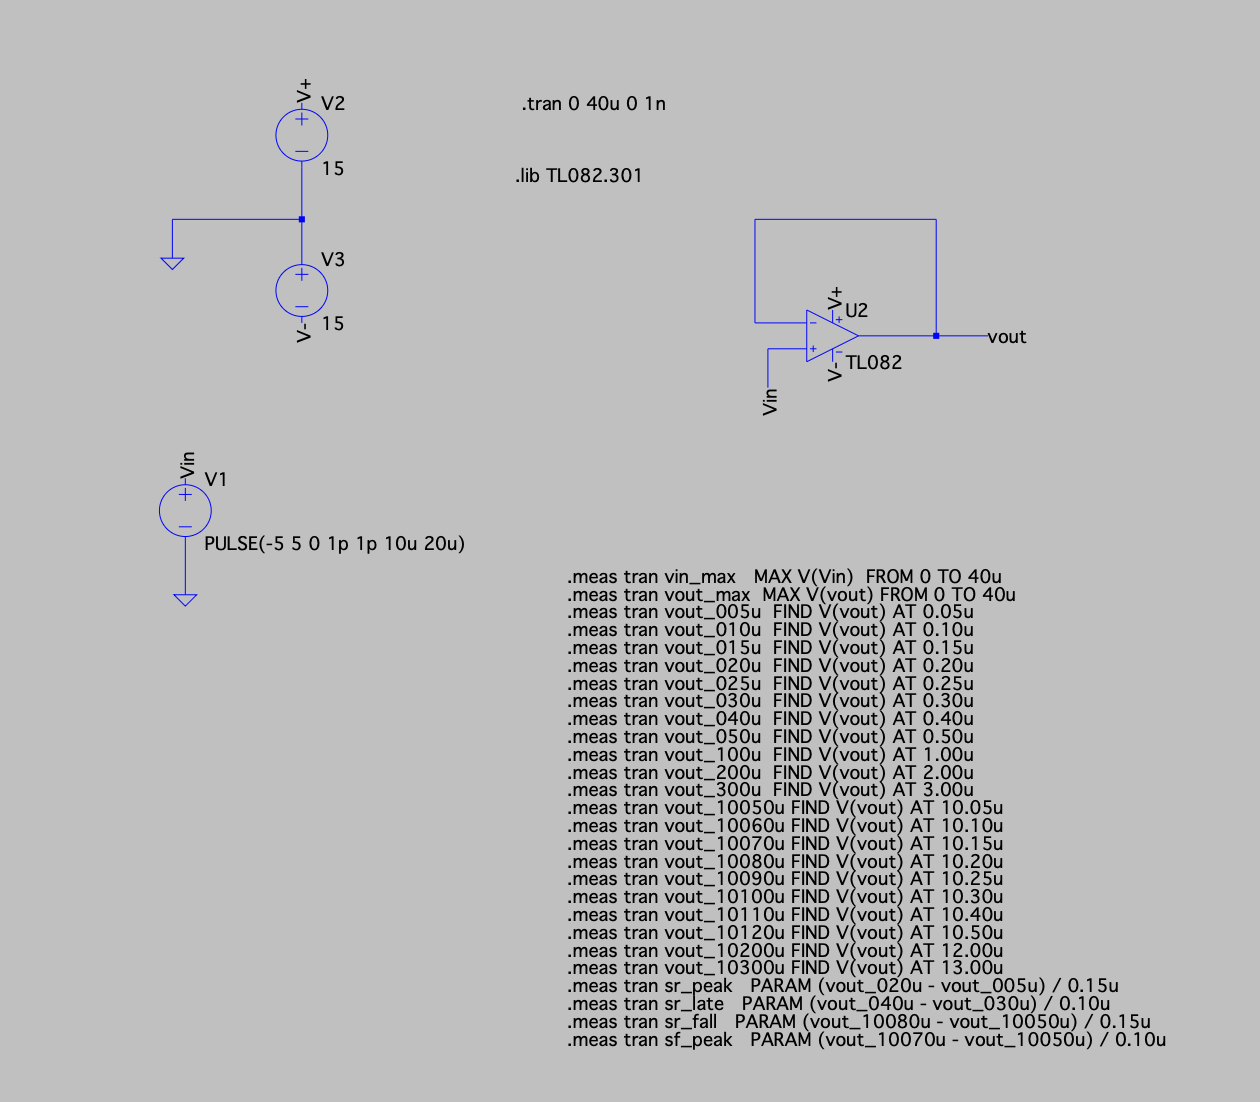
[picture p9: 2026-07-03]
ltspice/ltspice-simulation-1-buffer-slew-rate/schematic.png

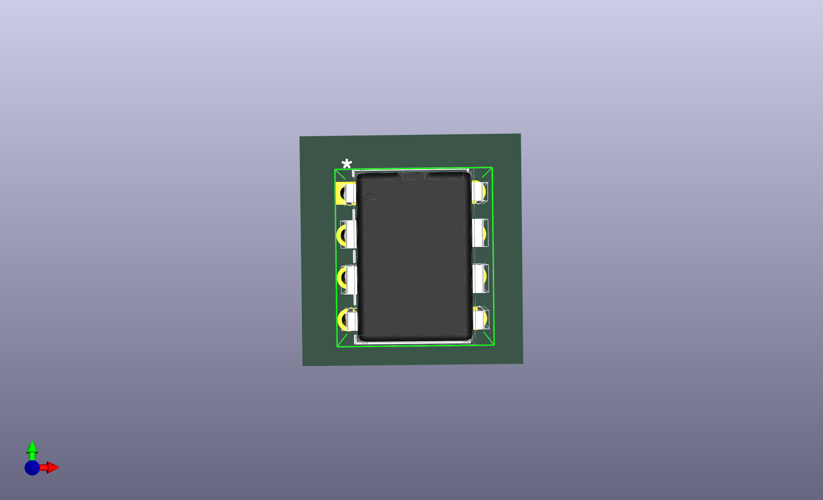
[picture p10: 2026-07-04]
docs/TL082CP.png

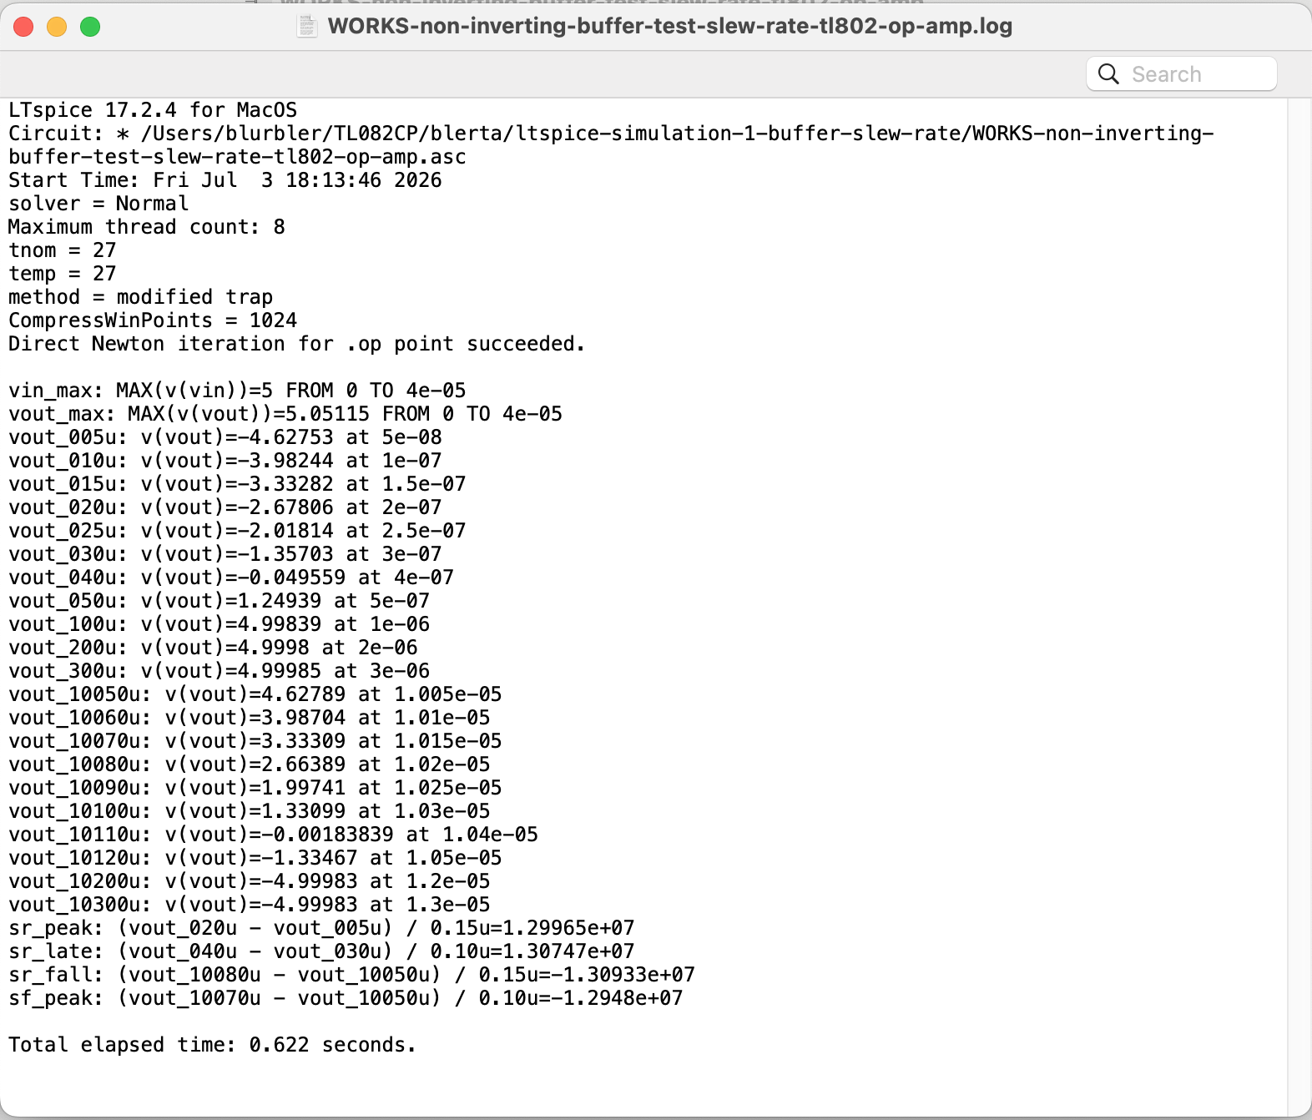
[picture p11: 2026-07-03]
ltspice/ltspice-simulation-1-buffer-slew-rate/errorlog.png

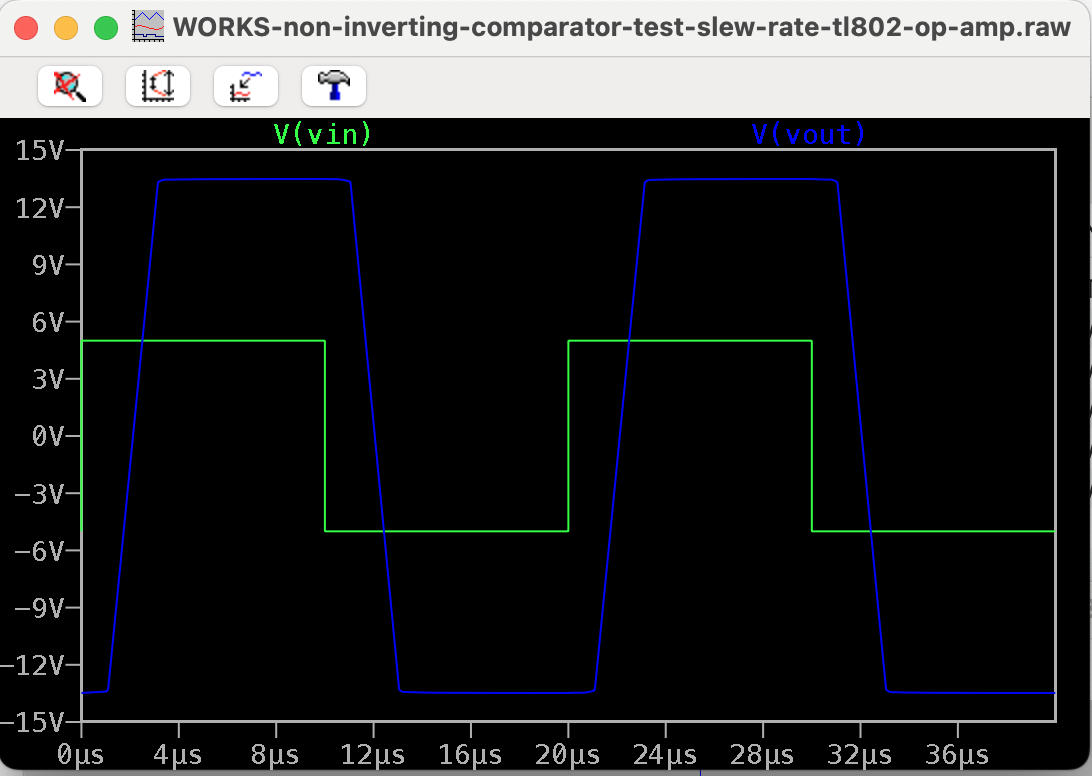
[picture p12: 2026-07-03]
ltspice/ltspice-simulation-1-comparator-slew-rate/plot.png

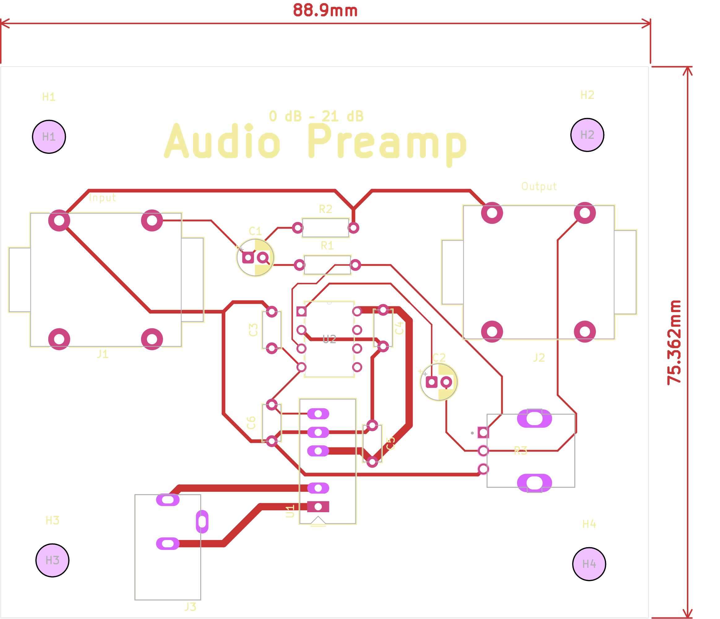
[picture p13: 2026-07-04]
mechanisch/TL082CP_PCB_2to1.png

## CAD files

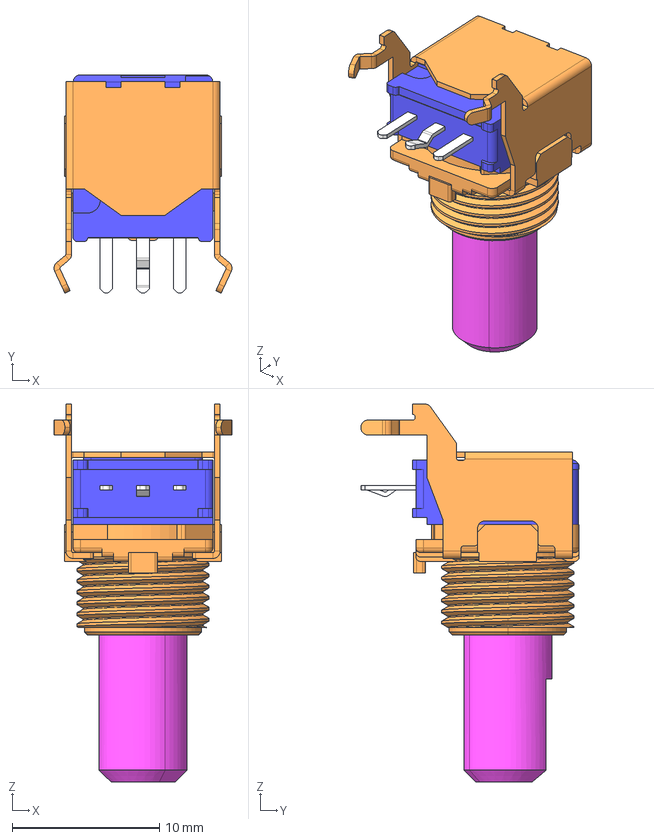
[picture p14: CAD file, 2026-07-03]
kicad/186517601-659-rk09l1120a2s/rk09l1120a2s.stp
12.1 x 14.8 x 25.7 mm

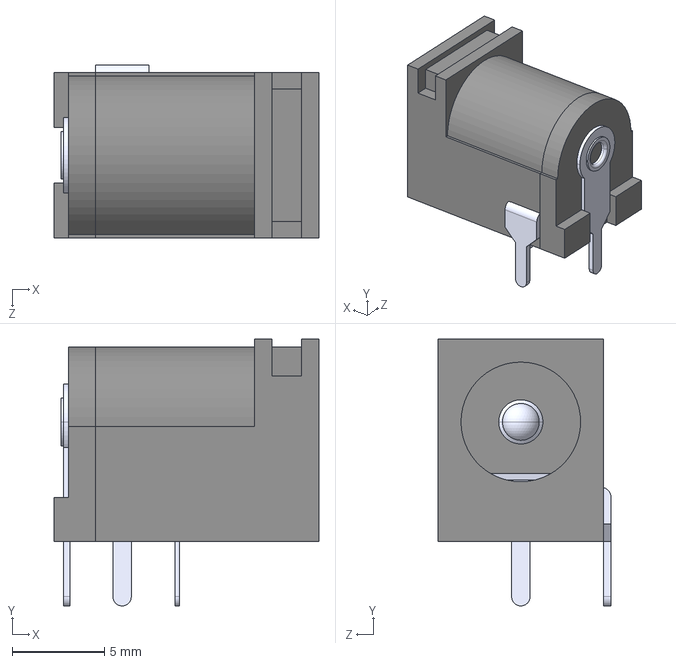
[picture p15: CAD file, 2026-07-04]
kicad/PJ-102A/PJ-102A.step
14.4 x 14.5 x 9.40 mm

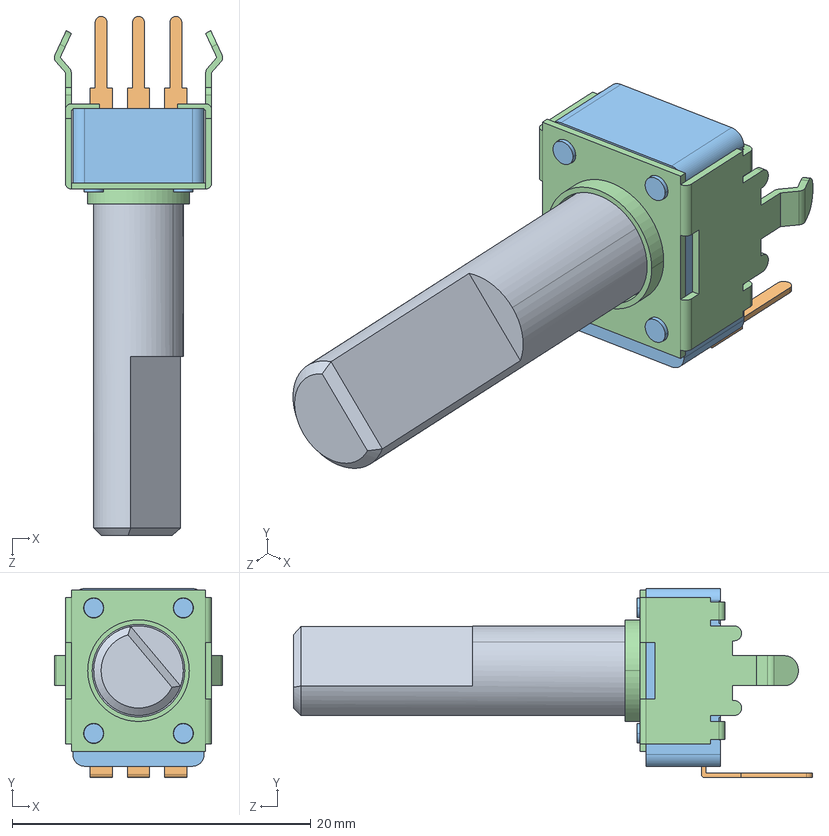
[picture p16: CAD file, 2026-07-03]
kicad/PT01-D130D-B503/PT01-D130D-B503.step
11.3 x 12.7 x 34.8 mm
PT01_30D_SHAFT
PT01-D_BODY
PT01-D_SHELL

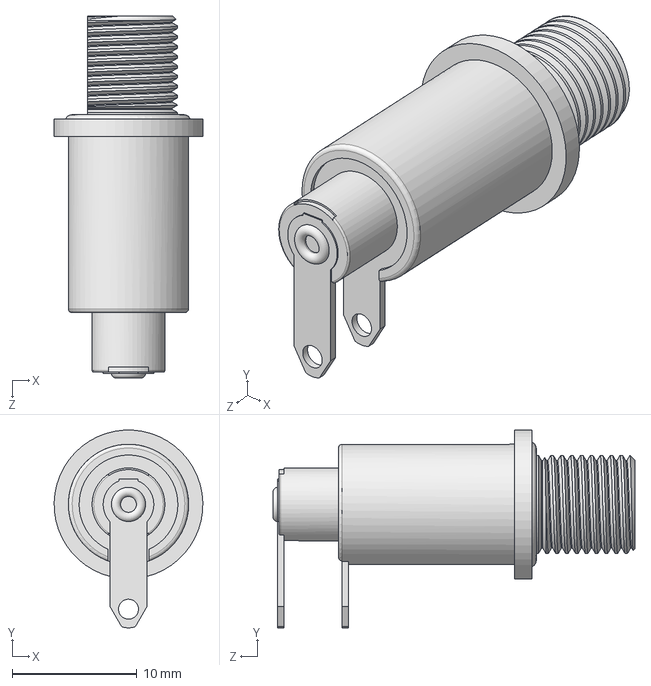
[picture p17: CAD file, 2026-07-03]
kicad/RAPC10U--3DModel-STEP-1.STEP
11.9 x 15.9 x 29.0 mm

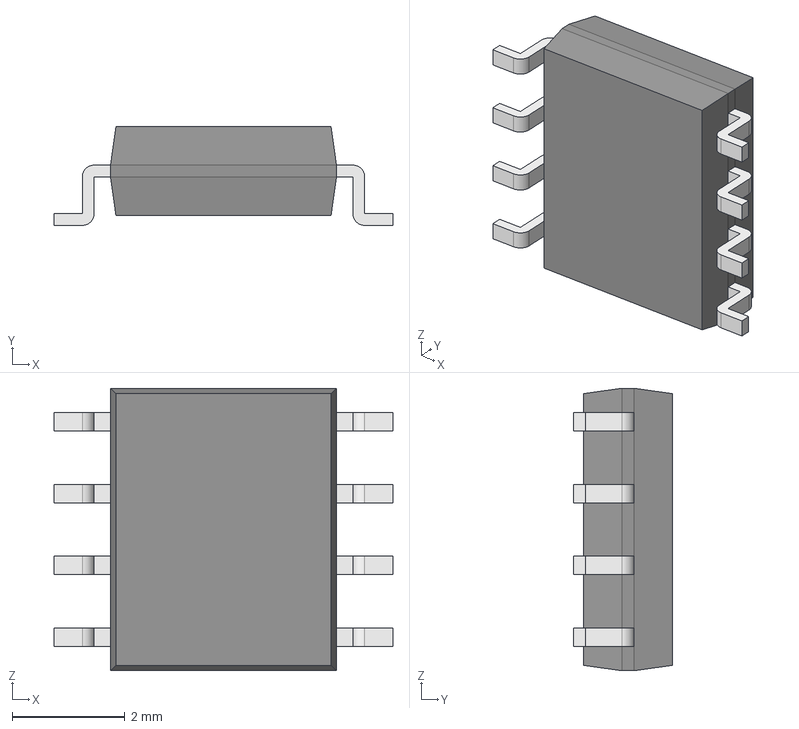
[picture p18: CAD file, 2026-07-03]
kicad/TL082-smd/TL082.step
6.00 x 1.75 x 5.00 mm
Body001 (Mirror #1) x 4
XY-plane x 12
X-axis x 12

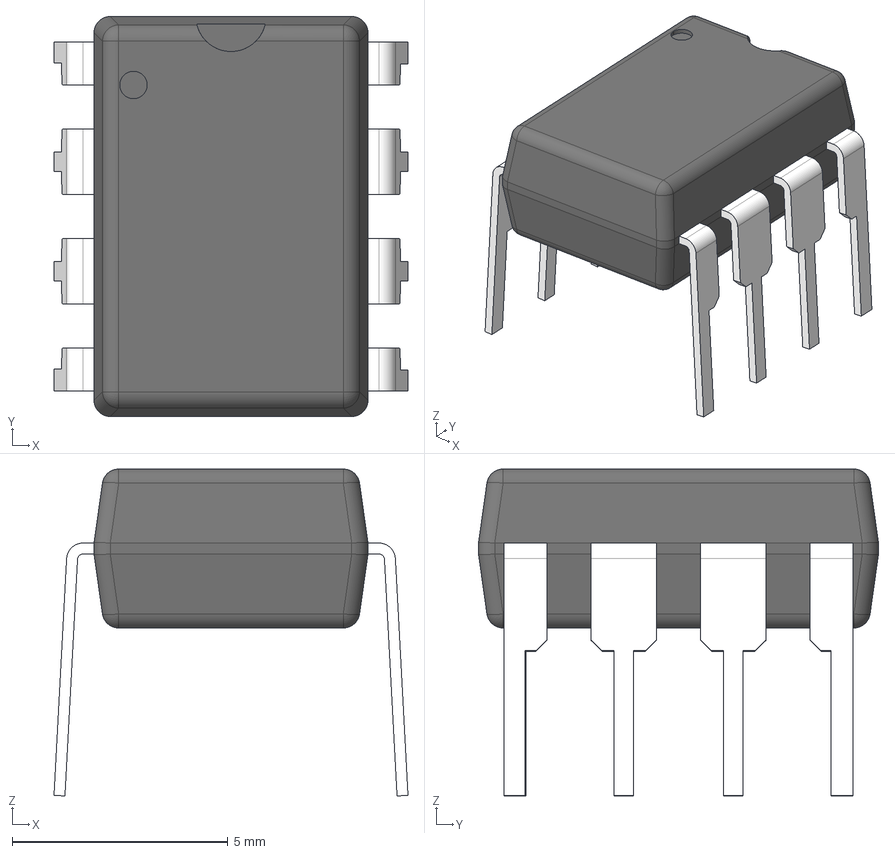
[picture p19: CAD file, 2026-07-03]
kicad/ul_TL082CP-NOPB/P0008A.stp
8.20 x 9.27 x 7.58 mm
BODY_P0008A
LEAD_P0008A x 4
LD_LHALF_P0008A x 2
LD_RHALF_P0008A x 2

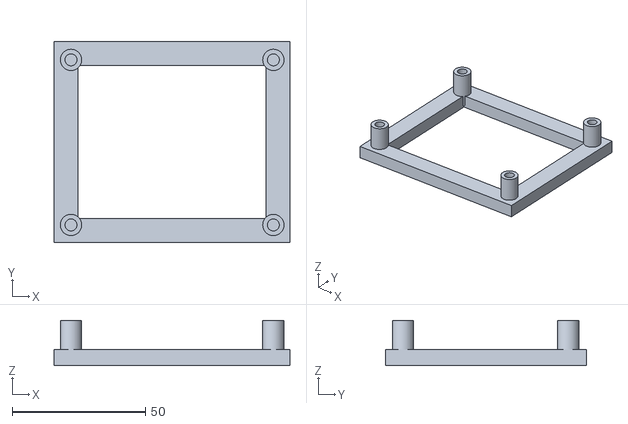
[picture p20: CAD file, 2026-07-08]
Mounting-platform-for-PCB.stl
88.6 x 75.4 x 17.0

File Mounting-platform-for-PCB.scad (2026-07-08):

// PCB Trägerplatte - TL082CP Audio Preamp
// Bolzen exakt auf PCB-Montagebohrungen positioniert

$fn=70;

// Platte = PCB-Größe (aus Edge_Cuts Gerber)
width   = 88.63;
length  = 75.36;
thickness=6;

// PCB-Montagelöcher (4.5 mm)
mount_drill = 4.5;

// Schraubbolzen-Außendurchmesser
bolt_d = 8;

// Positionen der PCB-Montagelöcher (relativ zur PCB-Ecke, aus NPTH-drl)
hole_x1 = 6.385;
hole_x2 = 82.385;
hole_y1 = 6.524;
hole_y2 = 68.524;

difference () {
    // Basisplatte
    cube([width, length, thickness]);

    // Ausschnitt Unterseite für Zugänglichkeit
    translate([thickness*1.5, thickness*1.5, -10])
        cube([width - 3*thickness, length - 3*thickness, 20]);

    // Flache Unterseite
    translate([0, 0, -2])
        cube([width+1, length+1, 2]);
}

// Bolzen an den 4 PCB-Montagepositionen
module bolt(x, y) {
    difference() {
        translate([x, y, 1])
            cylinder(d=bolt_d, h=thickness+10);
        translate([x, y, 1.1])
            cylinder(d=mount_drill, h=thickness+10);
    }
}

bolt(hole_x1, hole_y1);
bolt(hole_x2, hole_y1);
bolt(hole_x1, hole_y2);
bolt(hole_x2, hole_y2);

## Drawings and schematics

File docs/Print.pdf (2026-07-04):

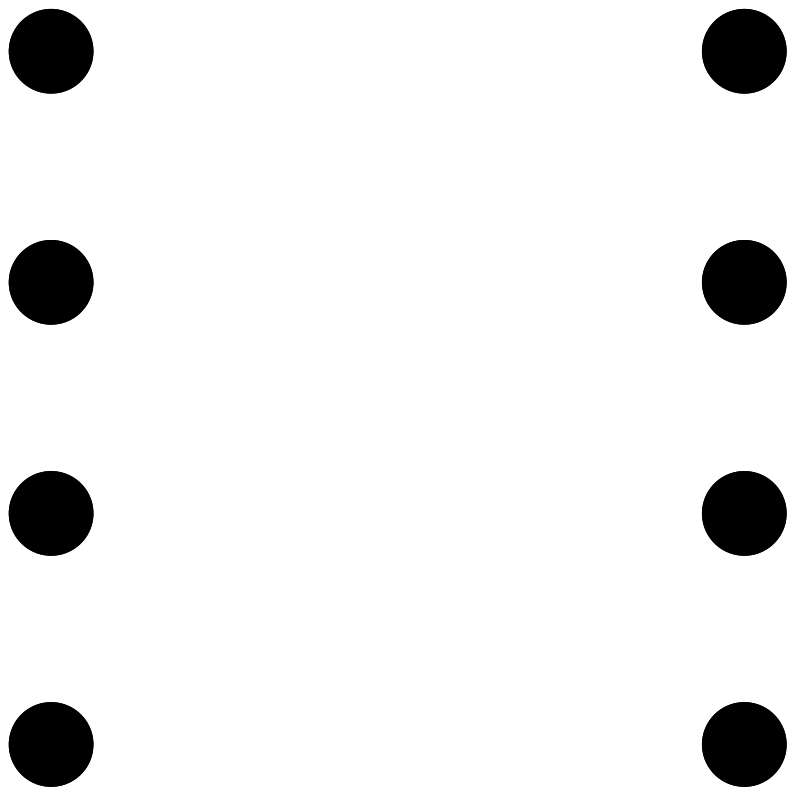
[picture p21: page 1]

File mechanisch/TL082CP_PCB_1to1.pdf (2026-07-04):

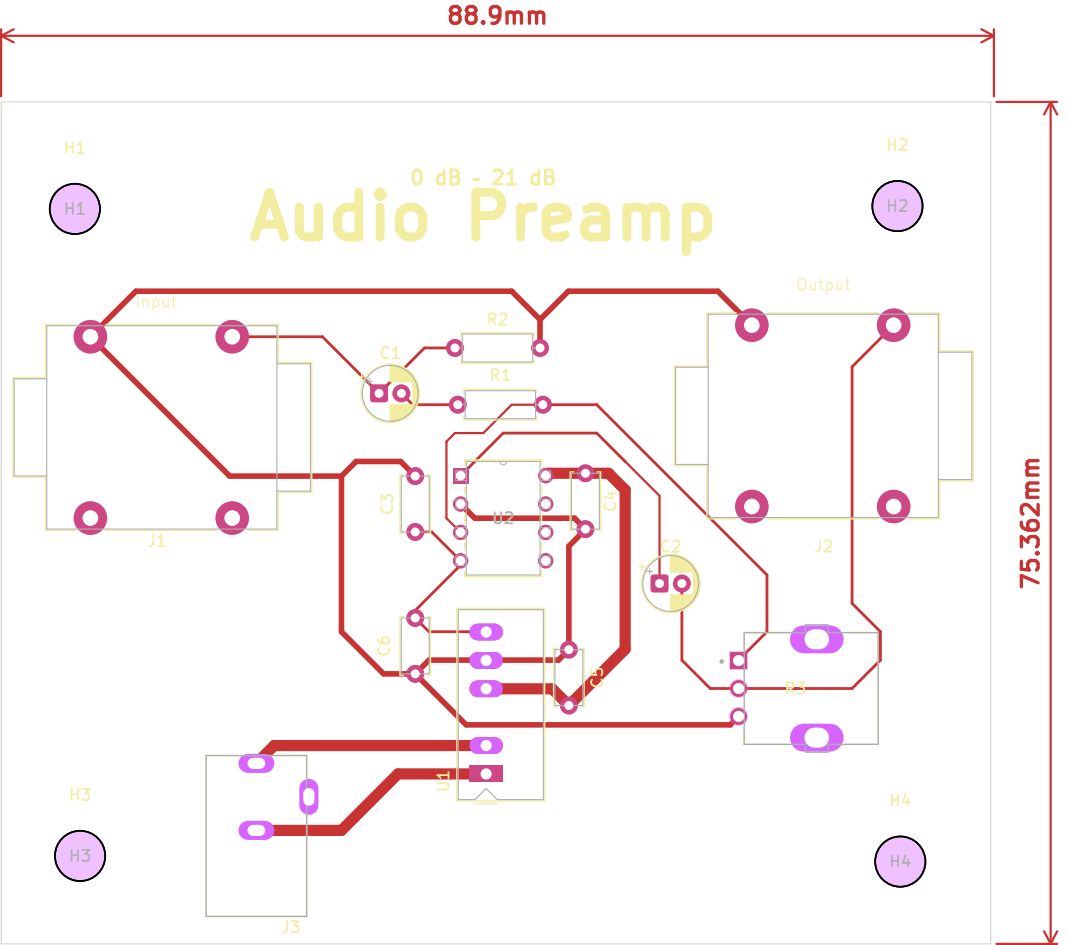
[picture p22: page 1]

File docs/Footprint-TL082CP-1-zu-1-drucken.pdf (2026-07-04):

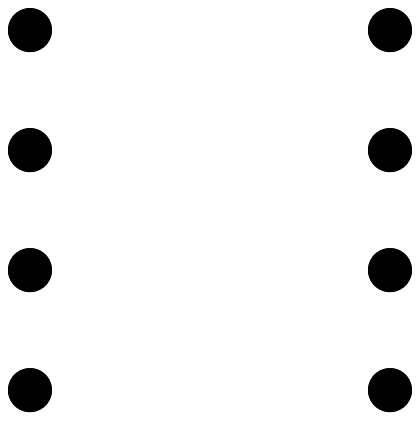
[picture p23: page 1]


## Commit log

2026-07-04 feat: pcb routing
    [TL082CP.kicad_pcb]
2026-07-04 fix: schematic capacitors, resistors, symbols updated
    [PJ-102A.step, TL082CP.kicad_sch, audio_signal.kicad_sch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]
2026-07-04 final pcb layout and updated doc
    [TL082CP.kicad_pcb, TL082CP.kicad_sch]
2026-07-04 feat: bauteilfigur zum ausdrucken
    [Mounting-platform-for-PCB.scad, TL082CP.kicad_pcb]
2026-07-04 feat: traegerplatte und pcb ausdrucke
    [Mounting-platform-for-PCB.scad, Mounting-platform-for-PCB.stl]
2026-07-04 feat: generated gerber and drill files, grid origin used as grid and drill origin
    [TL082CP-B_Cu.gbr, TL082CP-B_Mask.gbr, TL082CP-B_Paste.gbr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]
2026-07-08 fix: 3d models missing and slew rate 10-90 percent command
    [TL082CP.kicad_pcb]
2026-07-08 fix: ground plane
    [TL082CP.kicad_pcb]
2026-07-08 fix: align mounting holes
    [TL082CP.kicad_pcb]
2026-07-08 chore: regenerate drill files
    [TL082CP-B_Cu.gbr, TL082CP-B_Mask.gbr, TL082CP-B_Paste.gbr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]
2026-07-08 fix: mounting holes on platform
    [Mounting-platform-for-PCB.scad, Mounting-platform-for-PCB.stl]
2026-07-08 fix(kicad): move ground plane from User.1 to B.Cu layer
    The ground plane zone was incorrectly placed on User.1 documentation
    layer instead of B.Cu copper layer. Added README section explaining
    proper ground plane creation workflow for future reference.
    [Mounting-platform-for-PCB.scad, Mounting-platform-for-PCB.stl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]
